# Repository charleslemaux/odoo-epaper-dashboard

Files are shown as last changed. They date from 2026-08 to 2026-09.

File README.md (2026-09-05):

# Odoo e-Paper Dashboard — Pico 2 W, C firmware

Bare-metal C rewrite (Pico SDK, no OS, no dynamic allocation in project
code) of a MicroPython prototype. A Raspberry Pi Pico 2 W joins your WiFi,
authenticates against a self-hosted Odoo instance over HTTPS, and shows
the signed-in user's scheduled Activities (`mail.activity` — the items
behind the clock icon in Odoo's top bar, attached to any record: a
contact, an invoice, a task...) on a Waveshare 7.3" e-Paper HAT
(E) — Spectra 6, 800x480, 6 fixed colors (black, white, yellow, red,
blue, green).

It polls Odoo's JSON-RPC API every 5 minutes but only spends a physical
refresh cycle on the panel when the activity list actually changed, or once
a day for a mandatory health refresh. Spectra 6 panels have no
partial-refresh mode, so minimizing wear means minimizing *refreshes*,
not minimizing pixels touched. Everything runs from a single superloop
with static buffers; the only dynamic allocation anywhere is mbedTLS's
internal handshake scratch space, freed right after each TLS handshake.

Screen layout (800x480 — 72px banner with 48px title, seven 48px rows
of 32px text, 32px footer; rendered by the firmware's own code via
`make -C tests preview.exe`):

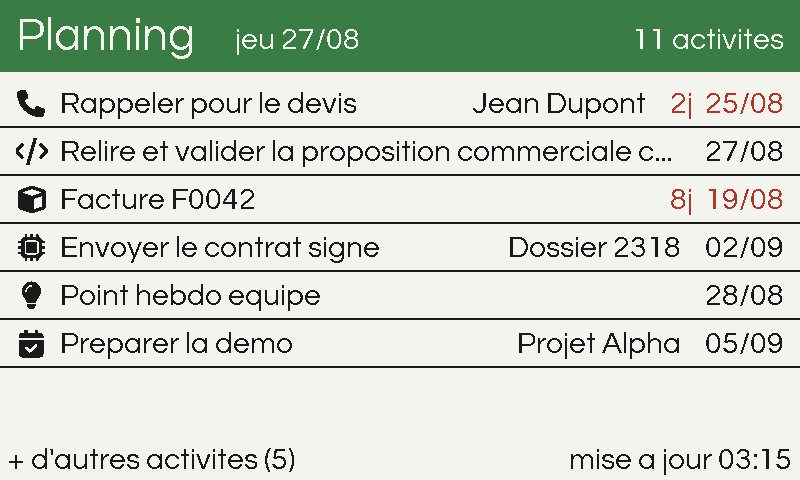
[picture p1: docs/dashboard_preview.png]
Dashboard layout


Each row starts with a 32px icon mirroring the Font Awesome icon
configured on the activity type in Odoo itself (the firmware fetches
each activity's `icon` class and maps it in `src/app/activity_icon.c`;
unknown classes fall back to a clock), then the
activity's summary (or, when the activity has no summary, the name of
the record it is attached to). The deadline (always visible, far
right) stays black until the date has passed and turns red once it
has, joined by a compact red day counter (`8j`). The text has priority
over the row: if it is too long it is truncated with `...`, otherwise
the remaining width shows the related record, right-aligned. Bold
full-width separators divide the rows. The banner counter shows the
real total of scheduled activities (fetched with a `search_count`
alongside the row query), and when more exist than the seven visible
rows the footer says how many are hidden: `+ d'autres activites (N)`. The footer shows the timestamp
of the last *screen update*, not a live clock (a ticking clock would
force a refresh every minute, defeating the whole point).

Text is set in [Questrial](https://fonts.google.com/specimen/Questrial)
(SIL Open Font License 1.1 — see `lib/questrial/OFL.txt`), pre-rendered
at build time into 32 px and 48 px proportional bitmap glyphs
(`src/gfx/font_data.c`, generated by `tools/gen_font.py`) since the
panel firmware has no TTF rasterizer. To change the font, drop a new
TTF in `lib/` and run
`python tools/gen_font.py lib/yourfont/YourFont.ttf`.

Activity-type icons are rasterized the same way from
[Font Awesome Free](https://fontawesome.com) solid glyphs (icons
CC BY 4.0, font SIL OFL 1.1 — see `lib/fontawesome/LICENSE.txt`) by
`tools/gen_icons.py` into `src/gfx/icon_data.c`. To support a new
custom activity type: add its glyph codepoint to `tools/gen_icons.py`,
its `fa-...` class to the table in `src/app/activity_icon.c`, rerun
the generator, and rebuild.

## 1. Hardware and wiring

- MCU: Raspberry Pi Pico 2 W (RP2350, 520 KB SRAM, CYW43439 WiFi). The
  "2 WH" (pre-soldered headers) variant is identical firmware-wise.
- Panel: Waveshare 7.3" e-Paper HAT (E), Spectra 6, 800x480.
- Bus: 4-wire SPI, but driven as bit-banged GPIO on purpose — hardware
  SPI at >= 1 MHz corrupts commands on this wiring (Dupont wires +
  ribbon cable). Do not "optimize" this back to hardware SPI without
  re-validating on real hardware; see `DRIVER_REFERENCE.md` section 2.
- **SPI Select switch on the HAT must be on 0.**

| Signal | Pico pin | Constant |
|---|---|---|
| VCC | 3V3 OUT (pin 36) | — |
| GND | GND | — |
| DIN | GP11 | `DIN_PIN`  |
| CLK | GP10 | `CLK_PIN`  |
| CS | GP9 | `CS_PIN` |
| DC | GP8 | `DC_PIN` |
| RST | GP12 | `RST_PIN`  |
| BUSY | GP13 | `BUSY_PIN` |

Panel safety rules, all enforced in the firmware but worth knowing:

- `epd_sleep()` is called after every refresh, on every code path
  including failures. Leaving the panel powered outside sleep mode
  holds it at high internal voltage and causes irreversible damage.
- At least 3 minutes between refreshes (`REFRESH_MIN_GAP_S = 180`).
- At least one refresh every 24 hours while powered
  (`REFRESH_MAX_AGE_S = 86400`).
- One `epd_display()` per fully-composed frame — never partial sends.

## 2. Toolchain setup, from zero

These are the packages the firmware actually needs to cross-compile for
the Pico 2 W (PowerShell, run as your normal user — no admin needed for
winget user-scope installs):

```powershell
winget install -e --id Kitware.CMake --accept-source-agreements --accept-package-agreements
winget install -e --id Ninja-build.Ninja --accept-package-agreements
winget install -e --id Arm.GnuArmEmbeddedToolchain --accept-package-agreements
```

Clone the Pico SDK (2.3.0 or any later stable 2.x tag) with its four
required submodules — the SDK itself is much bigger than these four, but
only these are needed for this project's WiFi/lwIP/mbedTLS/USB stack:

```powershell
git clone --depth 1 --branch 2.3.0 https://github.com/raspberrypi/pico-sdk.git $env:USERPROFILE\pico-sdk
cd $env:USERPROFILE\pico-sdk
git submodule update --init --depth 1 lib/cyw43-driver lib/lwip lib/mbedtls lib/tinyusb
```

Point the SDK at the ARM toolchain and the checkout (adjust the version
folder in the ARM path to whatever winget actually installed —
`Get-ChildItem 'C:\Program Files (x86)\Arm GNU Toolchain arm-none-eabi'`
will show it):

```powershell
[Environment]::SetEnvironmentVariable('PICO_SDK_PATH', "$env:USERPROFILE\pico-sdk", 'User')
[Environment]::SetEnvironmentVariable('PICO_TOOLCHAIN_PATH', 'C:\Program Files (x86)\Arm GNU Toolchain arm-none-eabi\14.2 rel1\bin', 'User')
```

Open a new terminal (persisted User environment variables are not
picked up by already-running shells), then verify:

```powershell
cmake --version
ninja --version
arm-none-eabi-gcc --version
```

Note: an earlier draft of this setup called for a bundled host
toolchain ("w64devkit") alongside the ARM one. That package does not
exist in the winget catalog, and the firmware itself never needs a host
compiler — CMake cross-compiles everything with the ARM toolchain
above. A host C compiler is only needed for two things, both covered
below: running the unit tests under `tests/`, and (rarely) building
`picotool` from source during the very first `cmake --build`.

### Host compiler for tests

`tests/` builds and runs on your PC, not the Pico, so it needs a plain
host C compiler and `make`. Any working gcc or clang is fine. On this
project's development machine, the obvious winget substitute for a host
gcc (`BrechtSanders.WinLibs.POSIX.UCRT`) turned out to have a bundled
assembler (`as.exe`) that Windows Smart App Control silently blocks
when it's invoked as a subprocess — which breaks every build that
depends on it, tests included, with a confusing "CreateProcess: No such
file or directory" error that has nothing to do with the actual code.
`clang` was installed as a working substitute instead:

```powershell
winget install -e --id LLVM.LLVM --accept-package-agreements
```

and tests are run with `CC=clang` (see "Host tests" below). If your
system gcc already works cleanly, plain `make -C tests run` is fine —
there is nothing gcc-specific about the test code.

## 3. Configuration

Copy the template and fill in real values — `include/config.h` is
gitignored from the first commit, so credentials can never be committed
by accident:

```powershell
cp config.h.example include/config.h
```

Fields, in the order they appear in `config.h.example`:

| Macro | Meaning |
|---|---|
| `WIFI_SSID` / `WIFI_PASSWORD` | Your WiFi network credentials. |
| `WIFI_COUNTRY` | A `CYW43_COUNTRY_*` constant from the Pico SDK (e.g. `CYW43_COUNTRY_FRANCE`); affects the legal WiFi channel set. |
| `ODOO_HOST` | Odoo hostname only — no `https://`, no path. |
| `ODOO_PORT` | HTTPS port, normally `443`. |
| `ODOO_DB` | Odoo database name. |
| `ODOO_LOGIN` | Your Odoo login (usually an email address). |
| `ODOO_API_KEY` | An Odoo API key (not your account password — see below). |
| `ODOO_ACTIVITY_DOMAIN` | A JSON-RPC domain filter on `mail.activity`, as a C string with `%d` where the authenticated `uid` goes (see below). |
| `POLL_INTERVAL_S` | Seconds between Odoo polls, default 300 (5 minutes). |
| `NTP_SERVER` | SNTP server for time sync, e.g. `pool.ntp.org`. |
| `TZ_OFFSET_MIN` | Local timezone offset from UTC, in minutes (no DST database — a plain fixed offset, adjust by hand across DST changes). |
| `EPD_CLK_HALF_PERIOD_US` | Bit-bang clock half-period in microseconds. Default `1` (~500 kHz effective). Do not lower this without re-validating on real hardware — see the SPI corruption warning in section 1. |

`ODOO_CA_CERT` is not in the template's macro list; it is documented as
an optional addition in a comment at the bottom of
`config.h.example` — see "Optional: pinning the Odoo CA certificate"
below.

**Keep `"` out of every config value.** All of these are compiled as C
string literals; an unescaped `"` inside a password, login, or hostname
will break the build (or silently truncate the value at best).

### Creating an Odoo API key

Use an API key, not your login password: in Odoo, click your user
avatar (top right) -> **My Profile** -> **Account Security** tab ->
**New API Key**. Give it a description, confirm, and copy the key
immediately — Odoo only shows it once.

### Tuning `ODOO_ACTIVITY_DOMAIN`

The domain is a JSON-RPC filter on `mail.activity`, `printf`-substituted
at request-build time: `%d` is replaced with the `uid` returned by
`authenticate`. The default,

```c
#define ODOO_ACTIVITY_DOMAIN "[[\"user_id\",\"=\",%d]]"
```

fetches exactly what Odoo's systray clock shows: every activity
scheduled for the signed-in user, on any record, ordered by deadline
(activities always carry one). To narrow it, extend the domain — for
example, only activities on contacts:

```c
#define ODOO_ACTIVITY_DOMAIN "[[\"user_id\",\"=\",%d],[\"res_model\",\"=\",\"res.partner\"]]"
```

No firmware code needs to change for this — it's a config-only edit.

## 4. Optional: pinning the Odoo CA certificate

By default `ODOO_CA_CERT` is undefined, which means TLS still encrypts
the connection but does **not** verify the server's identity — a LAN
man-in-the-middle could intercept the connection and read your Odoo API
key. To pin the CA and get full certificate verification, fetch the
certificate chain:

```
openssl s_client -connect ODOO_HOST:443 -showcerts
```

(run from Git Bash or WSL if `openssl` isn't on your Windows PATH).
Take the **last** `-----BEGIN CERTIFICATE-----` ... `-----END
CERTIFICATE-----` block printed (the top of the chain, i.e. the issuing
CA), and turn it into a single C string with explicit `\n` line breaks:

```c
#define ODOO_CA_CERT "-----BEGIN CERTIFICATE-----\n" \
    "MIIB...\n" \
    "...\n" \
    "-----END CERTIFICATE-----\n"
```

Add this to your local `include/config.h`. That file is gitignored and
is explicitly exempted from the project's single-line-macro style rule
for exactly this reason (see the comment in `config.h.example`) — a
multi-line PEM string is fine there.

## 5. Build and flash

```powershell
cmake -S . -B build -G Ninja
cmake --build build
```

The build fails fast with a clear `#error` if `include/config.h` is
missing (see section 3). The first configure also downloads and builds
`picotool` from source — needed to turn the linked ELF into
`.uf2`/`.bin`/`.hex` for RP2350 — which requires a working **native**
host C/C++ compiler (not the ARM cross toolchain). If that host
compiler is broken (this project hit exactly the Smart App
Control/`as.exe` issue described in section 2 here too, since picotool
also tried to use the WinLibs GCC install), build `picotool` once with
any other working host compiler (e.g. MSVC's `cl.exe`, if Visual Studio
is installed) and point CMake at the prebuilt install instead of
letting it build from source:

```powershell
cmake -S build/_deps/picotool-src -B <picotool-build-dir> -G Ninja `
    -DCMAKE_C_COMPILER=cl -DCMAKE_CXX_COMPILER=cl -DPICOTOOL_NO_LIBUSB=1 `
    -DPICO_SDK_PATH=$env:PICO_SDK_PATH `
    -DCMAKE_INSTALL_PREFIX=<picotool-install-dir> -DCMAKE_BUILD_TYPE=Release
cmake --build <picotool-build-dir> --config Release
cmake --install <picotool-build-dir> --config Release
Remove-Item -Recurse -Force build
cmake -S . -B build -G Ninja -DCMAKE_PREFIX_PATH="<picotool-install-dir>"
```

The configure log will then say `Using picotool from
<picotool-install-dir>/bin/picotool.exe` instead of building it from
source, and `cmake --build build` proceeds normally.

To flash: hold **BOOTSEL**, plug the Pico 2 W into USB, release BOOTSEL
once it shows up as a mass-storage drive (`RP2350`), then drag-and-drop
`build/epaper_dashboard.uf2` onto that drive. The board reboots and
starts running the firmware automatically.

Open a serial monitor at **115200 baud** on the Pico's USB serial port
to watch the staged boot log (WiFi connect, SNTP sync, Odoo
authenticate, task count, refresh decisions).

## 6. Host tests

```
make -C tests run
```

builds and runs the ten host-side unit test binaries (`test_harness`,
`test_json_str`, `test_odoo_parse`, `test_odoo_request`,
`test_time_fmt`, `test_http_util`, `test_refresh`, `test_gfx`,
`test_gfx_text`, `test_dashboard`) — plain C, no Pico SDK dependency,
covering `odoo_parse` against canned JSON (nominal tasks, empty list,
Odoo error objects, truncated JSON, oversized fields, accented text),
the refresh-decision matrix, graphics primitives, and dashboard layout.

On this project's development machine, plain `make -C tests run` fails
for the same Smart App Control reason described in section 2 (the
WinLibs GCC substitute's assembler is blocked), so tests were actually
run with:

```
make -C tests CC=clang run
```

Expect every line to read `<name>: OK` and the command to exit 0.

## 7. Behavior reference

- After boot (WiFi connect with exponential backoff, 5 s doubling to an
  80 s cap; SNTP time sync; one Odoo `authenticate` call caching the
  `uid`), the firmware polls Odoo's JSON-RPC API every
  `POLL_INTERVAL_S` seconds (default 300 = 5 minutes).
- The panel is refreshed only when the fetched task snapshot actually
  changed, or at least once per 24 hours, and never less than 3 minutes
  after the previous refresh — otherwise the display is left untouched
  and the panel takes zero wear.
- Three consecutive failed polls count as a state change: the firmware
  forces one refresh showing an offline footer (`HORS LIGNE depuis
  HH:MM`, in red). The next successful poll forces a refresh back to
  the normal view.
- A hardware watchdog (8 s) reboots the board if any code path stops
  feeding it — the WiFi connect/retry loop, the inter-poll idle wait,
  and the panel's busy-wait loop all feed it periodically, so normal
  operation never trips it; only a genuine hang does.
- If the WiFi chip itself fails to initialize at boot (before any SSID
  or password is even used), the onboard LED fast-blinks (on/off every
  100 ms) forever and the firmware never proceeds further. That pattern
  always means the WiFi chip did not come up — not a wrong SSID or
  password, which instead shows as an endless "wifi: retry" backoff in
  the serial log.
- The dashboard renders ASCII only: the vendored font has no accented
  glyphs, so French accented characters coming back from Odoo (é, è,
  à, ç, ...) are folded to their unaccented equivalent while parsing the
  JSON response; any other multi-byte UTF-8 sequence becomes `?`.

## 8. Troubleshooting

- **Panel completely unresponsive** (serial log shows "epd: panel not
  responding", or a boot-time `RuntimeError` in the MicroPython
  reference): almost always a loose Dupont wire on CLK/DIN/DC/CS, or
  the SPI Select switch not on 0. Full diagnostic order in
  `DRIVER_REFERENCE.md` section 6.
- **Text renders wrong or a glyph looks broken**: the font is
  pre-rendered bitmap data generated from the TTF — regenerate with
  `python tools/gen_font.py lib/questrial/Questrial-Regular.ttf` after
  any font change, then rebuild.
- **Build fails with `include/config.h missing`**: see section 3 — copy
  `config.h.example` there and fill it in.
- **LED fast-blinks forever right after power-on**: WiFi chip init
  failure (see "Behavior reference" above) — check the board/antenna,
  this is not a credentials problem.
- **Offline footer shows even though WiFi is clearly up**: check
  `ODOO_HOST`/`ODOO_PORT`/`ODOO_DB`/`ODOO_LOGIN`/`ODOO_API_KEY`, and
  whether `ODOO_ACTIVITY_DOMAIN` only uses `mail.activity` fields
  (see "Tuning `ODOO_ACTIVITY_DOMAIN`" in section 3).

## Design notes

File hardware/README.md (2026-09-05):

# Desk stand — Waveshare 7.3" e-Paper (E) + Pico 2 W (Rev 2.1)

Four flat 3D-printed parts, zero supports, zero glue, zero screws.
Every insertion path (not just the final positions) is verified by
boolean sweeps in `fusion_scripts/r8_motion.py` — if a part couldn't
physically slide or drop into place, the build fails loudly.

**How it goes together (all joints are slides or drop-ins):**

1. **panel → frame**: slides down from the frame's open top edge in
   its own plane, seats on the bottom ledge (exact vertical position),
   four side ribs center it with a light scratch-fit.
2. **plate → frame**: slides down the channel just behind the panel,
   dome-side toward the glass, under the side lips, clicks past two
   detents onto the stops. The six domes press the panel gently.
3. **screen module → base**: drops into the full-width 12° slot;
   gravity holds it; the ribbon falls through the notch behind the
   slot into the box.
4. **HAT / Pico → base**: drop into their fenced, labeled bays with
   all cables attached (HAT rests on two pedestals so its 40-pin
   socket hangs free; Pico lies loose; micro-USB cable exits the notch
   in the right wall).
5. **lid → base**: slides in through the rear-wall door until it hits
   the front stops; its ridge tail stays outside as the grip.

| File | What |
|---|---|
| `print/epaper73_H2C_PLA.3mf` | **Open in Bambu Studio → Slice → Print.** 4 parts arranged, H2C 0.4, 0.20mm Standard, Bambu PLA Basic, Textured PEI, supports OFF |
| `print/epaper73_*_print.stl` | Same four parts as pre-oriented STLs |
| `epaper73_case.step` | Full CAD + named `proxy_*` hardware reference bodies |
| `fusion_scripts/` | Regenerate/verify: `reset.py` → `r1_screen.py` → `r2_base.py` → `r3_check.py` (seated interference) → `r8_motion.py` (insertion sweeps) → `r4_export.py` → `make_print_meshes.py`. `r9_debug.py` probes material at specific spots; `r5/r6/r7/vis` pose explanatory views |

Window geometry uses the panel's real active-area offsets (borders
5.1 L/R, 4.7 top, 10.5 bottom per the Waveshare drawing) with the
panel *seated on the ledge*, so the visible area is deterministic.

## Printing (H2C, PLA)

All parts print as placed, flat side down, **no supports** (the only
overhangs are two 2.2 mm lip bridges in the frame and short lip strips
in the base — trivial bridging for the H2C). Keep filament shrinkage
at 100% and don't rescale; FDM clearances are modeled in: panel
+0.8/side (ribs re-center it), plate 0.5, screen slot 0.8, lid 0.2
thickness play, bays ≥0.8.

## Tuning (one constant each)

- Panel slides too hard/loose → rib reach in `r1_screen.py`
  (`85.0` in the rib boxes; ribs crush 0.1 nominal).
- Plate click too weak/strong → detent bump reach (`CH_X - 0.4`).
- Screen wobbles in slot → `SLOT_Y0/SLOT_Y1` in `r2_base.py` (gap 8.4
  vs frame 7.6).
- Lid slides hard → `LID_W` (175.0 in 175.2) or the door cut (±87.7).
- White border visible → `WIN_V0/WIN_V1/WIN_X` (active +0.8 reveal).

To reflash the Pico: slide the lid out, press BOOTSEL, replug.

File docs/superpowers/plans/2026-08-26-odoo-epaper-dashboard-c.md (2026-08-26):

# Odoo e-Paper Dashboard (C firmware) Implementation Plan

> **For agentic workers:** REQUIRED SUB-SKILL: Use superpowers:subagent-driven-development (recommended) or superpowers:executing-plans to implement this plan task-by-task. Steps use checkbox (`- [ ]`) syntax for tracking.

**Goal:** Bare-metal C firmware for a Raspberry Pi Pico 2 W that polls a self-hosted Odoo over HTTPS every 5 minutes and shows the user's open tasks on a Waveshare 7.3" Spectra-6 e-paper panel, refreshing only when data changes.

**Architecture:** Single-threaded superloop on the Pico SDK (`pico_cyw43_arch_lwip_poll`), lwIP `altcp_tls` + mbedTLS for HTTPS, hand-rolled HTTP/1.0 POST client, JSON-RPC to Odoo, jsmn-based parsing, custom 4bpp framebuffer graphics, and a C port of the validated MicroPython bit-bang panel driver (paced to ~500 kHz).

**Tech Stack:** Pico SDK 2.x (board `pico2_w`), CMake + Ninja + arm-none-eabi-gcc, lwIP, mbedTLS, jsmn (vendored), font8x8 (vendored), host tests via w64devkit gcc + make.

**Spec:** `docs/superpowers/specs/2026-08-26-odoo-epaper-dashboard-c-design.md`

## Global Constraints

- **Epitech C Coding Style v7 applies to every `.c`/`.h` in `src/`, `include/`, `tests/` and to `tests/Makefile`.** Vendored code in `lib/` is exempt. Key rules (violations are task failures):
  - snake_case everywhere; typedefs end `_t`; macros/global constants/enum members UPPER_SNAKE_CASE.
  - ≤ 80 columns; 4-space indent, never tabs (C files); LF line endings; no trailing spaces; file ends with exactly one newline.
  - Function bodies ≤ 20 lines; ≤ 4 parameters; per `.c` file ≤ 5 exported and ≤ 10 total functions; functions with no params take `void`.
  - Variables declared at top of function, one per statement, one blank line after declarations, no other blank lines inside functions; no comments inside function bodies.
  - Structs passed by pointer (C-F7); pointer `*` sticks to the name (C-V3); `const` wherever the data isn't modified (C-A1).
  - `if/else if/else` ≤ 3 branches; nesting depth ≤ 2 (an `else if` counts as 2); no `goto`; ternaries only simple and value-used.
  - Structure/enum declarations, prototypes, macros live in headers only (C-H1); include guards `#ifndef NAME_H_` (never `#pragma once`); preprocessor directives indented 4 spaces per level of *directive* nesting, independent of C code (C-G3).
  - Global variables forbidden; use `static` locals inside functions for persistent buffers; file-local helpers are `static` (C-A4). `static const` lookup tables inside `.c` files are accepted.
  - One statement per line (C-L1); exactly one empty line between function definitions (C-G2).
- **Every** `.c`/`.h` file starts with this exact header (adapt the description line):

```c
/*
** EPITECH PROJECT, 2026
** epaper_dashboard
** File description:
** <one-line description of the file>
*/
```

  `tests/Makefile` uses the `##` comment variant of the same header.
- **No dynamic allocation in project code.** Large/persistent buffers are `static` locals. mbedTLS allocates internally — that's allowed.
- **Build gates:** host-testable modules must pass `make -C tests run` (gcc, `-Wall -Wextra -Werror`); firmware tasks must produce `build/epaper_dashboard.uf2` via `cmake --build build`. Firmware compiles with `-Wall -Wextra` (no `-Werror` — SDK sources compile inside our target).
- **Hardware checkpoints** are marked `[HW]`: build the .uf2, then ask the user to flash (BOOTSEL drag-drop) and paste serial output. Do NOT block later software tasks on `[HW]` confirmation — continue and batch hardware validation at Task 19.
- **Environment facts** (verified 2026-08-26): Windows 11; `winget` and `python` (3.13) available; `cmake`, `ninja`, `arm-none-eabi-gcc`, `gcc`, `make` all missing; no pico-sdk anywhere. `winget`/env-var commands run in PowerShell; git/curl/build commands work in Bash. After `[Environment]::SetEnvironmentVariable(...,'User')`, also set the variable in the current session (`$env:X = ...`) — new values don't apply retroactively.
- **Documented deviations from the spec** (approved rationale, reconcile in spec later if desired):
  1. TLS certificate *time-validity* is not checked (`MBEDTLS_HAVE_TIME` off — avoids newlib clock syscall plumbing); CA chain + SNI hostname are still verified when `ODOO_CA_CERT` is set. SNTP remains required for dates/clock display.
  2. Footer overflow indicator is the generic `+ d'autres taches` (an exact `+N` would need a second Odoo query, out of scope).
  3. `ODOO_CA_CERT` is *defined-or-absent* in `config.h` (checked with `#ifdef`) instead of a `NULL` sentinel — avoids `-Waddress` warnings.
  4. Extra files beyond the spec's list, forced by the ≤10-functions rule: `jsmn_util.c`, `http_conn.c`, `sys_idle.c`, `include/app.h`.

---

### Task 1: Toolchain bootstrap

**Files:** none in repo (installs tools, clones SDK, sets env vars).

**Interfaces:**
- Consumes: nothing.
- Produces: working `cmake`, `ninja`, `arm-none-eabi-gcc`, host `gcc` + `make`; `C:\Users\charl\pico-sdk` with submodules; user env vars `PICO_SDK_PATH`, `PICO_TOOLCHAIN_PATH`.

- [ ] **Step 1: Install the four toolchain packages (PowerShell)**

```powershell
winget install -e --id Kitware.CMake --accept-source-agreements --accept-package-agreements
winget install -e --id Ninja-build.Ninja --accept-package-agreements
winget install -e --id Arm.GnuArmEmbeddedToolchain --accept-package-agreements
winget install -e --id skeeto.w64devkit --accept-package-agreements
```

If a winget ID is not found, search (`winget search cmake`, `winget search "arm gnu"`, `winget search w64devkit`) and install the matching package. Any working host gcc+make (e.g. MSYS2) is an acceptable substitute for w64devkit.

- [ ] **Step 2: Wire up PATH / env vars (PowerShell)**

Ninja lands in `%LOCALAPPDATA%\Microsoft\WinGet\Links` (already on PATH). CMake installs to `C:\Program Files\CMake\bin` — add to user PATH if `cmake --version` fails. Then:

```powershell
$armRoot = 'C:\Program Files (x86)\Arm GNU Toolchain arm-none-eabi'
$arm = (Get-ChildItem $armRoot | Sort-Object Name | Select-Object -Last 1).FullName + '\bin'
[Environment]::SetEnvironmentVariable('PICO_TOOLCHAIN_PATH', $arm, 'User')
$w64 = (Get-ChildItem "$env:LOCALAPPDATA\Microsoft\WinGet\Packages" -Directory -Filter '*w64devkit*' | Select-Object -First 1).FullName
$w64bin = (Get-ChildItem $w64 -Recurse -Directory -Filter bin | Select-Object -First 1).FullName
[Environment]::SetEnvironmentVariable('Path', [Environment]::GetEnvironmentVariable('Path','User') + ';' + $w64bin, 'User')
```

Adapt discovery paths to what the installers actually did (`Get-ChildItem` first). Also set `$env:Path`/`$env:PICO_TOOLCHAIN_PATH` in-session before verifying.

- [ ] **Step 3: Clone the Pico SDK (Bash)**

```bash
git ls-remote --tags https://github.com/raspberrypi/pico-sdk.git | grep -o 'refs/tags/2\.[0-9.]*$' | sort -V | tail -3
# pick the highest stable 2.x.y tag printed, e.g. 2.1.1:
git clone --depth 1 --branch <TAG> https://github.com/raspberrypi/pico-sdk.git /c/Users/charl/pico-sdk
cd /c/Users/charl/pico-sdk
git submodule update --init --depth 1 lib/cyw43-driver lib/lwip lib/mbedtls lib/tinyusb
```

```powershell
[Environment]::SetEnvironmentVariable('PICO_SDK_PATH', 'C:\Users\charl\pico-sdk', 'User')
```

- [ ] **Step 4: Verify everything**

Run (fresh env in-session): `cmake --version`, `ninja --version`, `arm-none-eabi-gcc --version` (use `$env:PICO_TOOLCHAIN_PATH\arm-none-eabi-gcc.exe` if not on PATH — that's fine, the SDK uses the env var), `gcc --version`, `make --version`, `ls $env:PICO_SDK_PATH/pico_sdk_init.cmake`.
Expected: all print versions / the file exists. Nothing to commit.

---

### Task 2: Repository scaffold

**Files:**
- Create: `.gitattributes`, `config.h.example`, `micropython/` (moved files)
- Modify: none.

**Interfaces:**
- Consumes: nothing.
- Produces: `config.h.example` — the exact macro set every later module's `#include "config.h"` relies on.

- [ ] **Step 1: Move MicroPython reference files (Bash)**

```bash
cd /c/Users/charl/Documents/GitHub/e-paper_pico-2W
mkdir -p micropython src include lib tests
git mv main.py dashboard.py tutorial.md micropython/
```

(`DRIVER_REFERENCE.md` stays at repo root — it documents hardware truth the C driver uses.)

- [ ] **Step 2: Create `.gitattributes`**

```
* text=auto
*.c text eol=lf
*.h text eol=lf
*.md text eol=lf
*.py text eol=lf
Makefile text eol=lf
CMakeLists.txt text eol=lf
*.cmake text eol=lf
```

- [ ] **Step 3: Create `config.h.example`**

```c
/*
** EPITECH PROJECT, 2026
** epaper_dashboard
** File description:
** Configuration template: copy to include/config.h and fill in real values
*/

#ifndef CONFIG_H_
    #define CONFIG_H_

#define WIFI_SSID "MyNetwork"
#define WIFI_PASSWORD "MyPassword"
#define WIFI_COUNTRY CYW43_COUNTRY_FRANCE
#define ODOO_HOST "odoo.example.com"
#define ODOO_PORT 443
#define ODOO_DB "mydb"
#define ODOO_LOGIN "me@example.com"
#define ODOO_API_KEY "paste-api-key-here"
#define ODOO_TASK_DOMAIN "[[\"user_ids\",\"in\",[%d]],[\"is_closed\",\"=\",false]]"
#define POLL_INTERVAL_S 300
#define NTP_SERVER "pool.ntp.org"
#define TZ_OFFSET_MIN 120
#define EPD_CLK_HALF_PERIOD_US 1

/*
** Optional: TLS certificate pinning. When ODOO_CA_CERT is NOT defined the
** connection is encrypted but the server certificate is NOT verified.
** To pin your CA, define it as one C string with \n separators, e.g.:
** #define ODOO_CA_CERT "-----BEGIN CERTIFICATE-----\nMIIB...\n" \
**     "...\n-----END CERTIFICATE-----\n"
** (Your personal include/config.h is gitignored and exempt from the
** single-line-macro style rule.)
*/

#endif /* !CONFIG_H_ */
```

- [ ] **Step 4: Commit**

```bash
git add .gitattributes config.h.example
git commit -m "chore: scaffold repo layout, line-ending policy and config template"
```

(Include the standard trailer block from Global Constraints in this and every commit.)

---

### Task 3: Firmware skeleton builds a .uf2

**Files:**
- Create: `CMakeLists.txt`, `pico_sdk_import.cmake` (copied from SDK), `src/main.c` (stub, replaced in Tasks 15/19).

**Interfaces:**
- Consumes: Task 1 toolchain + `PICO_SDK_PATH`.
- Produces: `build/epaper_dashboard.uf2`; the CMake target `epaper_dashboard` that later tasks extend.

- [ ] **Step 1: Copy the SDK import shim (Bash)**

```bash
cp "$PICO_SDK_PATH/external/pico_sdk_import.cmake" pico_sdk_import.cmake
```

- [ ] **Step 2: Create `CMakeLists.txt`**

```cmake
cmake_minimum_required(VERSION 3.13)

set(PICO_BOARD pico2_w CACHE STRING "Board type")
include(pico_sdk_import.cmake)

project(epaper_dashboard C CXX ASM)
set(CMAKE_C_STANDARD 11)

pico_sdk_init()

add_executable(epaper_dashboard
    src/main.c
)

target_include_directories(epaper_dashboard PRIVATE
    ${CMAKE_CURRENT_LIST_DIR}
    ${CMAKE_CURRENT_LIST_DIR}/include
    ${CMAKE_CURRENT_LIST_DIR}/lib/jsmn
    ${CMAKE_CURRENT_LIST_DIR}/lib/font8x8
)

target_compile_options(epaper_dashboard PRIVATE -Wall -Wextra)

target_link_libraries(epaper_dashboard
    pico_stdlib
)

pico_enable_stdio_usb(epaper_dashboard 1)
pico_enable_stdio_uart(epaper_dashboard 0)
pico_add_extra_outputs(epaper_dashboard)
```

- [ ] **Step 3: Create stub `src/main.c`**

```c
/*
** EPITECH PROJECT, 2026
** epaper_dashboard
** File description:
** Entry point (toolchain-check stub, replaced by the real superloop later)
*/

#include <stdio.h>
#include "pico/stdlib.h"

int main(void)
{
    stdio_init_all();
    for (;;) {
        printf("epaper_dashboard: toolchain OK\n");
        sleep_ms(1000);
    }
    return 0;
}
```

- [ ] **Step 4: Build**

```bash
cmake -S . -B build -G Ninja
cmake --build build
ls build/epaper_dashboard.uf2
```

Expected: `.uf2` exists. First configure downloads picotool — allow it.

- [ ] **Step 5 [HW]:** Offer the user to flash this stub (BOOTSEL drag-drop, serial monitor 115200 should print `toolchain OK`). Do not block on it.

- [ ] **Step 6: Commit**

```bash
git add CMakeLists.txt pico_sdk_import.cmake src/main.c
git commit -m "feat: minimal Pico 2 W firmware skeleton builds a uf2"
```

---

### Task 4: Vendored libraries + host test harness

**Files:**
- Create: `lib/jsmn/jsmn.h`, `lib/font8x8/font8x8_basic.h`, `tests/Makefile`, `tests/test_config/config.h`, `tests/test_harness.c`.

**Interfaces:**
- Consumes: host gcc + make (Task 1).
- Produces: `make -C tests run` convention; `tests/test_config/config.h` fake credentials all request-builder tests compile against; jsmn (`jsmntok_t`, `jsmn_parse`) and `font8x8_basic[128][8]` for later tasks.

- [ ] **Step 1: Vendor the two single-header libraries (Bash)**

```bash
curl -fsSL https://raw.githubusercontent.com/zserge/jsmn/master/jsmn.h -o lib/jsmn/jsmn.h
curl -fsSL https://raw.githubusercontent.com/dhepper/font8x8/master/font8x8_basic.h -o lib/font8x8/font8x8_basic.h
grep -q jsmn_parse lib/jsmn/jsmn.h && grep -q font8x8_basic lib/font8x8/font8x8_basic.h && echo VENDOR_OK
```

Expected: `VENDOR_OK`. (jsmn: MIT license; font8x8: public domain — keep their headers intact. `font8x8_basic.h` defines a non-static array: it must be included by exactly one `.c` file, `src/gfx_text.c`.)

- [ ] **Step 2: Create `tests/test_config/config.h`** (fake credentials, same shape as `config.h.example`)

```c
/*
** EPITECH PROJECT, 2026
** epaper_dashboard
** File description:
** Fake configuration used by host-side unit tests only
*/

#ifndef CONFIG_H_
    #define CONFIG_H_

#define WIFI_SSID "test-ssid"
#define WIFI_PASSWORD "test-pass"
#define ODOO_HOST "odoo.test.lan"
#define ODOO_PORT 443
#define ODOO_DB "testdb"
#define ODOO_LOGIN "tester@test.lan"
#define ODOO_API_KEY "test-key"
#define ODOO_TASK_DOMAIN "[[\"user_ids\",\"in\",[%d]]]"
#define POLL_INTERVAL_S 300
#define NTP_SERVER "pool.ntp.org"
#define TZ_OFFSET_MIN 120
#define EPD_CLK_HALF_PERIOD_US 1

#endif /* !CONFIG_H_ */
```

- [ ] **Step 3: Create `tests/test_harness.c`** (proves the harness itself works)

```c
/*
** EPITECH PROJECT, 2026
** epaper_dashboard
** File description:
** Smoke test proving the host test harness compiles and runs
*/

#include <assert.h>
#include <stdio.h>
#include "config.h"

int main(void)
{
    assert(ODOO_PORT == 443);
    printf("test_harness: OK\n");
    return 0;
}
```

- [ ] **Step 4: Create `tests/Makefile`**

```make
##
## EPITECH PROJECT, 2026
## epaper_dashboard
## File description:
## Host-side unit test build and runner (gcc + make from w64devkit)
##

CC = gcc
CFLAGS = -Wall -Wextra -Werror -std=gnu11 -Itest_config -I../include \
	-I../lib/jsmn -I../lib/font8x8

TESTS = test_harness

all: $(addsuffix .exe,$(TESTS))

test_harness.exe: test_harness.c
	$(CC) $(CFLAGS) -o $@ $^

run: all
	for t in $(TESTS); do ./$$t.exe || exit 1; done

clean:
	rm -f *.exe
```

(Recipe lines use real tabs — mandatory in make. Each later task appends its own rule and extends `TESTS`.)

- [ ] **Step 5: Run** `make -C tests run` — Expected: `test_harness: OK`.

- [ ] **Step 6: Commit**

```bash
git add lib tests
git commit -m "feat: vendor jsmn and font8x8, add host test harness"
```

---

### Task 5: `json_str` — JSON string extraction with ASCII folding

**Files:**
- Create: `include/json_str.h`, `src/json_str.c`, `tests/test_json_str.c`
- Modify: `tests/Makefile`

**Interfaces:**
- Consumes: nothing (pure C, no Pico deps).
- Produces: `void json_str_fold(char *dst, size_t size, char const *src, size_t len);` — decodes a raw JSON string token (`src`/`len` = bytes between the quotes, escapes intact), folds UTF-8 and `\uXXXX` to ASCII (é→e, œ→oe, …), always NUL-terminates, and marks truncation by making the last kept char `'.'`.

- [ ] **Step 1: Write the failing test `tests/test_json_str.c`**

```c
/*
** EPITECH PROJECT, 2026
** epaper_dashboard
** File description:
** Unit tests for JSON string extraction and ASCII folding
*/

#include <assert.h>
#include <stdio.h>
#include <string.h>
#include "json_str.h"

static void test_plain_ascii(void)
{
    char out[16];

    json_str_fold(out, sizeof(out), "hello", 5);
    assert(strcmp(out, "hello") == 0);
}

static void test_unicode_escape(void)
{
    char out[16];

    json_str_fold(out, sizeof(out), "caf\\u00e9", 9);
    assert(strcmp(out, "cafe") == 0);
}

static void test_raw_utf8(void)
{
    char out[16];

    json_str_fold(out, sizeof(out), "d\xc3\xa9j\xc3\xa0 vu", 9);
    assert(strcmp(out, "deja vu") == 0);
}

static void test_escapes(void)
{
    char out[16];

    json_str_fold(out, sizeof(out), "a\\\"b\\\\c\\nd", 10);
    assert(strcmp(out, "a\"b\\c d") == 0);
}

static void test_truncation(void)
{
    char out[6];

    json_str_fold(out, sizeof(out), "abcdefgh", 8);
    assert(strcmp(out, "abcd.") == 0);
}

static void test_oe_ligature(void)
{
    char out[16];

    json_str_fold(out, sizeof(out), "c\xc5\x93ur", 5);
    assert(strcmp(out, "coeur") == 0);
}

int main(void)
{
    test_plain_ascii();
    test_unicode_escape();
    test_raw_utf8();
    test_escapes();
    test_truncation();
    test_oe_ligature();
    printf("test_json_str: OK\n");
    return 0;
}
```

- [ ] **Step 2: Extend `tests/Makefile`** — set `TESTS = test_harness test_json_str` and append:

```make
test_json_str.exe: test_json_str.c ../src/json_str.c
	$(CC) $(CFLAGS) -o $@ $^
```

Run `make -C tests run`. Expected: FAIL (no such file `../src/json_str.c` / missing header).

- [ ] **Step 3: Create `include/json_str.h`**

```c
/*
** EPITECH PROJECT, 2026
** epaper_dashboard
** File description:
** JSON string token extraction with UTF-8 and escape folding to ASCII
*/

#ifndef JSON_STR_H_
    #define JSON_STR_H_

    #include <stddef.h>
    #include <stdint.h>

struct json_out {
    char *dst;
    size_t size;
    size_t pos;
};

struct fold_entry {
    uint32_t cp;
    char const *out;
};

void json_str_fold(char *dst, size_t size, char const *src, size_t len);

#endif /* !JSON_STR_H_ */
```

- [ ] **Step 4: Create `src/json_str.c`**

```c
/*
** EPITECH PROJECT, 2026
** epaper_dashboard
** File description:
** JSON string token extraction with UTF-8 and escape folding to ASCII
*/

#include "json_str.h"

static const struct fold_entry FOLD_TABLE[] = {
    {0xE0, "a"}, {0xE2, "a"}, {0xE4, "a"}, {0xE7, "c"}, {0xE8, "e"},
    {0xE9, "e"}, {0xEA, "e"}, {0xEB, "e"}, {0xEE, "i"}, {0xEF, "i"},
    {0xF4, "o"}, {0xF6, "o"}, {0xF9, "u"}, {0xFB, "u"}, {0xFC, "u"},
    {0xC0, "A"}, {0xC2, "A"}, {0xC7, "C"}, {0xC8, "E"}, {0xC9, "E"},
    {0xCA, "E"}, {0xCB, "E"}, {0xCE, "I"}, {0xCF, "I"}, {0xD4, "O"},
    {0xD9, "U"}, {0xDB, "U"}, {0x153, "oe"}, {0x152, "OE"},
    {0xE6, "ae"}, {0xC6, "AE"}, {0x2019, "'"}, {0x2013, "-"},
    {0x2014, "-"}, {0x2026, "..."}, {0, 0}
};

static int hex_val(char c)
{
    if (c >= '0' && c <= '9')
        return c - '0';
    if ((c | 32) >= 'a' && (c | 32) <= 'f')
        return (c | 32) - 'a' + 10;
    return -1;
}

static size_t decode_hex4(char const *src, uint32_t *cp)
{
    uint32_t value = 0;
    int digit = 0;

    for (size_t i = 0; i < 4; i++) {
        digit = hex_val(src[i]);
        if (digit < 0)
            return 0;
        value = (value << 4) | (uint32_t)digit;
    }
    *cp = value;
    return 4;
}

static size_t decode_escape(char const *src, size_t len, uint32_t *cp)
{
    *cp = '?';
    if (len < 1)
        return 0;
    if (*src == 'u' && len >= 5 && decode_hex4(src + 1, cp) == 4)
        return 5;
    if (*src == 'u')
        return len < 5 ? len : 5;
    if (*src == 'n' || *src == 'r' || *src == 't')
        *cp = ' ';
    if (*src == '"' || *src == '\\' || *src == '/')
        *cp = (uint32_t)*src;
    return 1;
}

static size_t utf8_len(uint8_t lead)
{
    if (lead < 0x80)
        return 1;
    if ((lead & 0xE0) == 0xC0)
        return 2;
    if ((lead & 0xF0) == 0xE0)
        return 3;
    if ((lead & 0xF8) == 0xF0)
        return 4;
    return 0;
}

static size_t decode_utf8(char const *src, size_t len, uint32_t *cp)
{
    size_t need = utf8_len((uint8_t)*src);
    uint32_t value = 0;

    *cp = '?';
    if ((uint8_t)*src < 0x80) {
        *cp = (uint8_t)*src;
        return 1;
    }
    if (need == 0 || need > len)
        return 1;
    value = (uint8_t)*src & (uint32_t)(0xFF >> (need + 1));
    for (size_t i = 1; i < need; i++) {
        if (((uint8_t)src[i] & 0xC0) != 0x80)
            return 1;
        value = (value << 6) | ((uint8_t)src[i] & 0x3F);
    }
    *cp = value;
    return need;
}

static char const *fold_codepoint(uint32_t cp)
{
    static char single[2];

    if (cp >= 0x20 && cp < 0x7F) {
        single[0] = (char)cp;
        single[1] = '\0';
        return single;
    }
    for (size_t i = 0; FOLD_TABLE[i].out != 0; i++) {
        if (FOLD_TABLE[i].cp == cp)
            return FOLD_TABLE[i].out;
    }
    return cp < 0x20 ? " " : "?";
}

static void append_char(struct json_out *out, char c)
{
    if (out->pos + 1 < out->size) {
        out->dst[out->pos] = c;
        out->pos++;
        return;
    }
    if (out->size > 1)
        out->dst[out->size - 2] = '.';
}

static void append_folded(struct json_out *out, char const *s)
{
    for (size_t i = 0; s[i] != '\0'; i++)
        append_char(out, s[i]);
}

void json_str_fold(char *dst, size_t size, char const *src, size_t len)
{
    struct json_out out = {dst, size, 0};
    size_t i = 0;
    uint32_t cp = 0;

    if (size == 0)
        return;
    while (i < len) {
        if (src[i] == '\\')
            i += 1 + decode_escape(src + i + 1, len - i - 1, &cp);
        else
            i += decode_utf8(src + i, len - i, &cp);
        append_folded(&out, fold_codepoint(cp));
    }
    dst[out.pos] = '\0';
}
```

- [ ] **Step 5: Run** `make -C tests run` — Expected: `test_json_str: OK`.

- [ ] **Step 6: Commit** — `git add include/json_str.h src/json_str.c tests` , message `feat: json string folding to ascii with escape and utf-8 support`.

---

### Task 6: `jsmn_util` + `odoo_parse` — response parsing

**Files:**
- Create: `include/jsmn_util.h`, `src/jsmn_util.c`, `include/odoo.h`, `include/odoo_parse.h`, `src/odoo_parse.c`, `tests/test_odoo_parse.c`
- Modify: `tests/Makefile`

**Interfaces:**
- Consumes: `json_str_fold` (Task 5), vendored `jsmn.h` (Task 4).
- Produces:
  - `struct jsmn_ctx { char const *json; size_t len; jsmntok_t const *toks; int count; };`
  - `int jsmn_util_parse(struct jsmn_ctx *ctx, jsmntok_t *toks, int max);` (caller pre-fills `json`+`len`; fills `toks`/`count`; returns count or -1)
  - `int jsmn_tok_eq(struct jsmn_ctx const *ctx, int idx, char const *s);`
  - `int jsmn_next_sibling(struct jsmn_ctx const *ctx, int idx);`
  - `int jsmn_find_key(struct jsmn_ctx const *ctx, char const *key);` (search root object, returns value index or -1)
  - `include/odoo.h`: `ODOO_MAX_TASKS` (12), `ODOO_FETCH_LIMIT` (13), `ODOO_REQ_CAP` (2048), `struct odoo_task { char name[64]; char project[32]; char deadline[11]; char stage[24]; unsigned int priority; };`, `struct odoo_task_list { unsigned int count; unsigned int overflow; struct odoo_task tasks[ODOO_MAX_TASKS]; };`
  - `int odoo_parse_auth(char const *json, size_t len, int *uid);` (0 ok / -1)
  - `int odoo_parse_tasks(char const *json, size_t len, struct odoo_task_list *list);` (0 ok / -1 parse error / -2 Odoo error object; always memsets `list` first)

- [ ] **Step 1: Write the failing test `tests/test_odoo_parse.c`**

```c
/*
** EPITECH PROJECT, 2026
** epaper_dashboard
** File description:
** Unit tests for Odoo JSON-RPC response parsing
*/

#include <assert.h>
#include <stdio.h>
#include <string.h>
#include "odoo_parse.h"

static const char SAMPLE_AUTH[] =
    "{\"jsonrpc\":\"2.0\",\"id\":1,\"result\":42}";
static const char SAMPLE_AUTH_FAIL[] =
    "{\"jsonrpc\":\"2.0\",\"id\":1,\"result\":false}";
static const char SAMPLE_ERROR[] = "{\"jsonrpc\":\"2.0\",\"id\":2,"
    "\"error\":{\"code\":200,\"message\":\"Odoo Server Error\"}}";
static const char SAMPLE_TASKS[] = "{\"jsonrpc\":\"2.0\",\"id\":2,"
    "\"result\":[{\"id\":7,\"name\":\"R\\u00e9parer le module\","
    "\"project_id\":[3,\"Compta\"],\"date_deadline\":\"2026-08-30\","
    "\"stage_id\":[2,\"En cours\"],\"priority\":\"1\"},"
    "{\"id\":8,\"name\":\"Deuxieme tache\",\"project_id\":false,"
    "\"date_deadline\":false,\"stage_id\":[1,\"A faire\"],"
    "\"priority\":\"0\"}]}";

static void test_auth(void)
{
    int uid = 0;

    assert(odoo_parse_auth(SAMPLE_AUTH, strlen(SAMPLE_AUTH), &uid) == 0);
    assert(uid == 42);
    assert(odoo_parse_auth(SAMPLE_AUTH_FAIL, strlen(SAMPLE_AUTH_FAIL),
        &uid) == -1);
    assert(odoo_parse_auth("garbage", 7, &uid) == -1);
}

static void test_tasks_nominal(void)
{
    struct odoo_task_list list;

    assert(odoo_parse_tasks(SAMPLE_TASKS, strlen(SAMPLE_TASKS),
        &list) == 0);
    assert(list.count == 2);
    assert(list.overflow == 0);
    assert(strcmp(list.tasks[0].name, "Reparer le module") == 0);
    assert(strcmp(list.tasks[0].project, "Compta") == 0);
    assert(strcmp(list.tasks[0].deadline, "2026-08-30") == 0);
    assert(strcmp(list.tasks[0].stage, "En cours") == 0);
    assert(list.tasks[0].priority == 1);
}

static void test_tasks_false_fields(void)
{
    struct odoo_task_list list;

    assert(odoo_parse_tasks(SAMPLE_TASKS, strlen(SAMPLE_TASKS),
        &list) == 0);
    assert(strcmp(list.tasks[1].project, "") == 0);
    assert(strcmp(list.tasks[1].deadline, "") == 0);
    assert(strcmp(list.tasks[1].stage, "A faire") == 0);
    assert(list.tasks[1].priority == 0);
}

static void test_error_and_garbage(void)
{
    struct odoo_task_list list;

    assert(odoo_parse_tasks(SAMPLE_ERROR, strlen(SAMPLE_ERROR),
        &list) == -2);
    assert(odoo_parse_tasks("not json at all", 15, &list) == -1);
}

static void build_many(char *dst, size_t size, int n)
{
    size_t pos = 0;

    pos += (size_t)snprintf(dst, size, "{\"result\":[");
    for (int i = 0; i < n; i++)
        pos += (size_t)snprintf(dst + pos, size - pos,
            "%s{\"id\":%d,\"name\":\"T%d\",\"priority\":\"0\"}",
            i > 0 ? "," : "", i, i);
    snprintf(dst + pos, size - pos, "]}");
}

static void test_overflow(void)
{
    static char json[4096];
    struct odoo_task_list list;

    build_many(json, sizeof(json), 13);
    assert(odoo_parse_tasks(json, strlen(json), &list) == 0);
    assert(list.count == 12);
    assert(list.overflow == 1);
    assert(strcmp(list.tasks[11].name, "T11") == 0);
}

int main(void)
{
    test_auth();
    test_tasks_nominal();
    test_tasks_false_fields();
    test_error_and_garbage();
    test_overflow();
    printf("test_odoo_parse: OK\n");
    return 0;
}
```

- [ ] **Step 2: Extend `tests/Makefile`** — `TESTS = test_harness test_json_str test_odoo_parse`, append:

```make
test_odoo_parse.exe: test_odoo_parse.c ../src/odoo_parse.c \
	../src/jsmn_util.c ../src/json_str.c
	$(CC) $(CFLAGS) -o $@ $^
```

Run: expected FAIL (missing files).

- [ ] **Step 3: Create `include/odoo.h`**

```c
/*
** EPITECH PROJECT, 2026
** epaper_dashboard
** File description:
** Odoo task data model shared by parsing, requests, refresh and rendering
*/

#ifndef ODOO_H_
    #define ODOO_H_

#define ODOO_MAX_TASKS 12
#define ODOO_FETCH_LIMIT (ODOO_MAX_TASKS + 1)
#define ODOO_REQ_CAP 2048

struct odoo_task {
    char name[64];
    char project[32];
    char deadline[11];
    char stage[24];
    unsigned int priority;
};

struct odoo_task_list {
    unsigned int count;
    unsigned int overflow;
    struct odoo_task tasks[ODOO_MAX_TASKS];
};

#endif /* !ODOO_H_ */
```

- [ ] **Step 4: Create `include/jsmn_util.h`**

```c
/*
** EPITECH PROJECT, 2026
** epaper_dashboard
** File description:
** Generic helpers over the jsmn token array
*/

#ifndef JSMN_UTIL_H_
    #define JSMN_UTIL_H_

    #include <stddef.h>
    #include "jsmn.h"

struct jsmn_ctx {
    char const *json;
    size_t len;
    jsmntok_t const *toks;
    int count;
};

int jsmn_util_parse(struct jsmn_ctx *ctx, jsmntok_t *toks, int max);
int jsmn_tok_eq(struct jsmn_ctx const *ctx, int idx, char const *s);
int jsmn_next_sibling(struct jsmn_ctx const *ctx, int idx);
int jsmn_find_key(struct jsmn_ctx const *ctx, char const *key);

#endif /* !JSMN_UTIL_H_ */
```

- [ ] **Step 5: Create `src/jsmn_util.c`** (NOTE: `#define JSMN_STATIC` **before** any include — this pulls the jsmn implementation into this one translation unit)

```c
/*
** EPITECH PROJECT, 2026
** epaper_dashboard
** File description:
** Generic helpers over the jsmn token array
*/

#define JSMN_STATIC
#include "jsmn.h"
#include <string.h>
#include "jsmn_util.h"

int jsmn_util_parse(struct jsmn_ctx *ctx, jsmntok_t *toks, int max)
{
    jsmn_parser parser;
    int count = 0;

    jsmn_init(&parser);
    count = jsmn_parse(&parser, ctx->json, ctx->len, toks,
        (unsigned int)max);
    if (count < 1)
        return -1;
    ctx->toks = toks;
    ctx->count = count;
    return count;
}

int jsmn_tok_eq(struct jsmn_ctx const *ctx, int idx, char const *s)
{
    jsmntok_t const *tok = &ctx->toks[idx];
    size_t len = (size_t)(tok->end - tok->start);

    if (tok->type != JSMN_STRING || strlen(s) != len)
        return 0;
    return strncmp(ctx->json + tok->start, s, len) == 0;
}

int jsmn_next_sibling(struct jsmn_ctx const *ctx, int idx)
{
    int end = ctx->toks[idx].end;
    int i = idx + 1;

    while (i < ctx->count && ctx->toks[i].start < end)
        i++;
    return i;
}

int jsmn_find_key(struct jsmn_ctx const *ctx, char const *key)
{
    int i = 1;

    if (ctx->count < 1 || ctx->toks[0].type != JSMN_OBJECT)
        return -1;
    while (i + 1 < ctx->count) {
        if (jsmn_tok_eq(ctx, i, key))
            return i + 1;
        i = jsmn_next_sibling(ctx, i + 1);
    }
    return -1;
}
```

- [ ] **Step 6: Create `include/odoo_parse.h`**

```c
/*
** EPITECH PROJECT, 2026
** epaper_dashboard
** File description:
** Odoo JSON-RPC response parsing into the task data model
*/

#ifndef ODOO_PARSE_H_
    #define ODOO_PARSE_H_

    #include <stddef.h>
    #include "odoo.h"

#define ODOO_MAX_JSON_TOKENS 512

int odoo_parse_auth(char const *json, size_t len, int *uid);
int odoo_parse_tasks(char const *json, size_t len,
    struct odoo_task_list *list);

#endif /* !ODOO_PARSE_H_ */
```

- [ ] **Step 7: Create `src/odoo_parse.c`**

```c
/*
** EPITECH PROJECT, 2026
** epaper_dashboard
** File description:
** Odoo JSON-RPC response parsing into the task data model
*/

#include <stdlib.h>
#include <string.h>
#include "jsmn_util.h"
#include "json_str.h"
#include "odoo_parse.h"

static void copy_tok(struct jsmn_ctx const *ctx, int idx, char *dst,
    size_t size)
{
    jsmntok_t const *tok = &ctx->toks[idx];

    dst[0] = '\0';
    if (idx < ctx->count && tok->type == JSMN_STRING)
        json_str_fold(dst, size, ctx->json + tok->start,
            (size_t)(tok->end - tok->start));
}

static void copy_relation(struct jsmn_ctx const *ctx, int idx, char *dst,
    size_t size)
{
    dst[0] = '\0';
    if (ctx->toks[idx].type == JSMN_ARRAY && ctx->toks[idx].size >= 2)
        copy_tok(ctx, idx + 2, dst, size);
}

static unsigned int priority_of(struct jsmn_ctx const *ctx, int idx)
{
    jsmntok_t const *tok = &ctx->toks[idx];

    if (tok->type == JSMN_STRING || tok->type == JSMN_PRIMITIVE)
        return ctx->json[tok->start] == '1';
    return 0;
}

static void set_task_field(struct jsmn_ctx const *ctx, int key,
    struct odoo_task *task)
{
    int val = key + 1;

    if (jsmn_tok_eq(ctx, key, "name"))
        copy_tok(ctx, val, task->name, sizeof(task->name));
    if (jsmn_tok_eq(ctx, key, "date_deadline"))
        copy_tok(ctx, val, task->deadline, sizeof(task->deadline));
    if (jsmn_tok_eq(ctx, key, "project_id"))
        copy_relation(ctx, val, task->project, sizeof(task->project));
    if (jsmn_tok_eq(ctx, key, "stage_id"))
        copy_relation(ctx, val, task->stage, sizeof(task->stage));
    if (jsmn_tok_eq(ctx, key, "priority"))
        task->priority = priority_of(ctx, val);
}

static void parse_task(struct jsmn_ctx const *ctx, int idx,
    struct odoo_task *task)
{
    int child = idx + 1;
    int pairs = ctx->toks[idx].size;

    for (int n = 0; n < pairs; n++) {
        set_task_field(ctx, child, task);
        child = jsmn_next_sibling(ctx, child + 1);
    }
}

static void parse_task_array(struct jsmn_ctx const *ctx, int idx,
    struct odoo_task_list *list)
{
    int child = idx + 1;
    int total = ctx->toks[idx].size;

    for (int n = 0; n < total; n++) {
        if (n < ODOO_MAX_TASKS)
            parse_task(ctx, child, &list->tasks[n]);
        child = jsmn_next_sibling(ctx, child);
    }
    list->count = total > ODOO_MAX_TASKS ? ODOO_MAX_TASKS
        : (unsigned int)total;
    list->overflow = total > ODOO_MAX_TASKS;
}

int odoo_parse_auth(char const *json, size_t len, int *uid)
{
    static jsmntok_t toks[64];
    struct jsmn_ctx ctx = {json, len, 0, 0};
    int val = 0;

    if (jsmn_util_parse(&ctx, toks, 64) < 0)
        return -1;
    val = jsmn_find_key(&ctx, "result");
    if (val < 0 || val >= ctx.count
        || ctx.toks[val].type != JSMN_PRIMITIVE)
        return -1;
    if (json[ctx.toks[val].start] < '0'
        || json[ctx.toks[val].start] > '9')
        return -1;
    *uid = atoi(json + ctx.toks[val].start);
    return 0;
}

int odoo_parse_tasks(char const *json, size_t len,
    struct odoo_task_list *list)
{
    static jsmntok_t toks[ODOO_MAX_JSON_TOKENS];
    struct jsmn_ctx ctx = {json, len, 0, 0};
    int val = 0;

    memset(list, 0, sizeof(*list));
    if (jsmn_util_parse(&ctx, toks, ODOO_MAX_JSON_TOKENS) < 0)
        return -1;
    if (jsmn_find_key(&ctx, "error") >= 0)
        return -2;
    val = jsmn_find_key(&ctx, "result");
    if (val < 0 || val >= ctx.count || ctx.toks[val].type != JSMN_ARRAY)
        return -1;
    parse_task_array(&ctx, val, list);
    return 0;
}
```

(`odoo_parse_auth` relies on the caller NUL-terminating the buffer for `atoi` — `http_client` guarantees this, and test strings are literals.)

- [ ] **Step 8: Run** `make -C tests run` — Expected: all OK.

- [ ] **Step 9: Commit** — `feat: parse odoo auth and task responses via jsmn`.

---

### Task 7: `odoo_request` — JSON-RPC request builders

**Files:**
- Create: `include/odoo_request.h`, `src/odoo_request.c`, `tests/test_odoo_request.c`
- Modify: `tests/Makefile`

**Interfaces:**
- Consumes: `config.h` macros (`ODOO_DB`, `ODOO_LOGIN`, `ODOO_API_KEY`, `ODOO_TASK_DOMAIN`), `ODOO_FETCH_LIMIT` from `odoo.h`.
- Produces: `int odoo_build_auth(char *dst, size_t size);` and `int odoo_build_tasks(char *dst, size_t size, int uid);` — both return body length, or -1 if truncated.

- [ ] **Step 1: Write the failing test `tests/test_odoo_request.c`**

```c
/*
** EPITECH PROJECT, 2026
** epaper_dashboard
** File description:
** Unit tests for Odoo JSON-RPC request body builders
*/

#include <assert.h>
#include <stdio.h>
#include <string.h>
#include "odoo_request.h"

static void test_auth_body(void)
{
    char body[512];
    int len = odoo_build_auth(body, sizeof(body));

    assert(len > 0);
    assert((size_t)len == strlen(body));
    assert(strstr(body, "\"service\":\"common\"") != 0);
    assert(strstr(body, "\"authenticate\"") != 0);
    assert(strstr(body, "\"testdb\"") != 0);
    assert(strstr(body, "\"tester@test.lan\"") != 0);
    assert(strstr(body, "\"test-key\"") != 0);
}

static void test_tasks_body(void)
{
    char body[2048];
    int len = odoo_build_tasks(body, sizeof(body), 42);

    assert(len > 0);
    assert(strstr(body, "\"execute_kw\"") != 0);
    assert(strstr(body, "\"project.task\"") != 0);
    assert(strstr(body, "\"search_read\"") != 0);
    assert(strstr(body, "[[\"user_ids\",\"in\",[42]]]") != 0);
    assert(strstr(body, "\"limit\":13") != 0);
    assert(strstr(body, "date_deadline asc, priority desc") != 0);
}

static void test_truncation(void)
{
    char body[32];

    assert(odoo_build_auth(body, sizeof(body)) == -1);
    assert(odoo_build_tasks(body, sizeof(body), 1) == -1);
}

int main(void)
{
    test_auth_body();
    test_tasks_body();
    test_truncation();
    printf("test_odoo_request: OK\n");
    return 0;
}
```

- [ ] **Step 2: Extend `tests/Makefile`** — add `test_odoo_request` to `TESTS`, append:

```make
test_odoo_request.exe: test_odoo_request.c ../src/odoo_request.c
	$(CC) $(CFLAGS) -o $@ $^
```

Run: expected FAIL.

- [ ] **Step 3: Create `include/odoo_request.h`**

```c
/*
** EPITECH PROJECT, 2026
** epaper_dashboard
** File description:
** Odoo JSON-RPC request body builders
*/

#ifndef ODOO_REQUEST_H_
    #define ODOO_REQUEST_H_

    #include <stddef.h>

int odoo_build_auth(char *dst, size_t size);
int odoo_build_tasks(char *dst, size_t size, int uid);

#endif /* !ODOO_REQUEST_H_ */
```

- [ ] **Step 4: Create `src/odoo_request.c`**

```c
/*
** EPITECH PROJECT, 2026
** epaper_dashboard
** File description:
** Odoo JSON-RPC request body builders
*/

#include <stdio.h>
#include "config.h"
#include "odoo.h"
#include "odoo_request.h"

static const char AUTH_TEMPLATE[] = "{\"jsonrpc\":\"2.0\","
    "\"method\":\"call\",\"params\":{\"service\":\"common\","
    "\"method\":\"authenticate\",\"args\":[\"%s\",\"%s\",\"%s\",{}]},"
    "\"id\":1}";

static const char TASKS_TEMPLATE[] = "{\"jsonrpc\":\"2.0\","
    "\"method\":\"call\",\"params\":{\"service\":\"object\","
    "\"method\":\"execute_kw\",\"args\":[\"%s\",%d,\"%s\","
    "\"project.task\",\"search_read\",[%s],{\"fields\":[\"name\","
    "\"project_id\",\"date_deadline\",\"stage_id\",\"priority\"],"
    "\"limit\":%d,\"order\":\"date_deadline asc, priority desc\"}]},"
    "\"id\":2}";

int odoo_build_auth(char *dst, size_t size)
{
    int written = snprintf(dst, size, AUTH_TEMPLATE, ODOO_DB, ODOO_LOGIN,
        ODOO_API_KEY);

    if (written < 0 || (size_t)written >= size)
        return -1;
    return written;
}

int odoo_build_tasks(char *dst, size_t size, int uid)
{
    char domain[256];
    int written = snprintf(domain, sizeof(domain), ODOO_TASK_DOMAIN, uid);

    if (written < 0 || (size_t)written >= sizeof(domain))
        return -1;
    written = snprintf(dst, size, TASKS_TEMPLATE, ODOO_DB, uid,
        ODOO_API_KEY, domain, ODOO_FETCH_LIMIT);
    if (written < 0 || (size_t)written >= size)
        return -1;
    return written;
}
```

- [ ] **Step 5: Run** `make -C tests run` — Expected: all OK.
- [ ] **Step 6: Commit** — `feat: build odoo authenticate and search_read request bodies`.

---

### Task 8: `time_fmt` — date/time formatting and deadline classification

**Files:**
- Create: `include/time_fmt.h`, `src/time_fmt.c`, `tests/test_time_fmt.c`
- Modify: `tests/Makefile`

**Interfaces:**
- Consumes: `<time.h>` only.
- Produces:
  - `enum deadline_class { DL_NONE = 0, DL_OVERDUE, DL_SOON, DL_NORMAL };`
  - `void time_fmt_banner(char *dst, size_t size, struct tm const *lt);` → `"mar 26/08"` (French day abbrevs, tm_wday 0=dim)
  - `void time_fmt_hhmm(char *dst, size_t size, struct tm const *lt);` → `"14:35"`
  - `void time_fmt_ddmm(char *dst, size_t size, char const *iso);` → `"30/08"` from `"2026-08-30"`, `"--"` when empty/short
  - `int time_fmt_deadline_class(char const *iso, struct tm const *today);`

- [ ] **Step 1: Write the failing test `tests/test_time_fmt.c`**

```c
/*
** EPITECH PROJECT, 2026
** epaper_dashboard
** File description:
** Unit tests for date formatting and deadline classification
*/

#include <assert.h>
#include <stdio.h>
#include <string.h>
#include <time.h>
#include "time_fmt.h"

static struct tm make_date(int year, int month, int day)
{
    struct tm t = {0};

    t.tm_year = year - 1900;
    t.tm_mon = month - 1;
    t.tm_mday = day;
    t.tm_hour = 12;
    mktime(&t);
    return t;
}

static void test_banner_and_hhmm(void)
{
    struct tm t = make_date(2026, 8, 26);
    char buf[16];

    t.tm_hour = 14;
    t.tm_min = 5;
    time_fmt_banner(buf, sizeof(buf), &t);
    assert(strcmp(buf, "mer 26/08") == 0);
    time_fmt_hhmm(buf, sizeof(buf), &t);
    assert(strcmp(buf, "14:05") == 0);
}

static void test_ddmm(void)
{
    char buf[8];

    time_fmt_ddmm(buf, sizeof(buf), "2026-08-30");
    assert(strcmp(buf, "30/08") == 0);
    time_fmt_ddmm(buf, sizeof(buf), "");
    assert(strcmp(buf, "--") == 0);
}

static void test_deadline_class(void)
{
    struct tm today = make_date(2026, 8, 26);

    assert(time_fmt_deadline_class("2026-08-25", &today) == DL_OVERDUE);
    assert(time_fmt_deadline_class("2026-08-26", &today) == DL_SOON);
    assert(time_fmt_deadline_class("2026-08-27", &today) == DL_SOON);
    assert(time_fmt_deadline_class("2026-08-28", &today) == DL_NORMAL);
    assert(time_fmt_deadline_class("", &today) == DL_NONE);
}

static void test_month_rollover(void)
{
    struct tm today = make_date(2026, 8, 31);

    assert(time_fmt_deadline_class("2026-09-01", &today) == DL_SOON);
    assert(time_fmt_deadline_class("2026-09-02", &today) == DL_NORMAL);
}

int main(void)
{
    test_banner_and_hhmm();
    test_ddmm();
    test_deadline_class();
    test_month_rollover();
    printf("test_time_fmt: OK\n");
    return 0;
}
```

- [ ] **Step 2: Extend `tests/Makefile`** — add `test_time_fmt` to `TESTS`, append:

```make
test_time_fmt.exe: test_time_fmt.c ../src/time_fmt.c
	$(CC) $(CFLAGS) -o $@ $^
```

Run: expected FAIL.

- [ ] **Step 3: Create `include/time_fmt.h`**

```c
/*
** EPITECH PROJECT, 2026
** epaper_dashboard
** File description:
** Date and time formatting helpers plus deadline classification
*/

#ifndef TIME_FMT_H_
    #define TIME_FMT_H_

    #include <stddef.h>
    #include <time.h>

enum deadline_class {
    DL_NONE = 0,
    DL_OVERDUE,
    DL_SOON,
    DL_NORMAL,
};

void time_fmt_banner(char *dst, size_t size, struct tm const *lt);
void time_fmt_hhmm(char *dst, size_t size, struct tm const *lt);
void time_fmt_ddmm(char *dst, size_t size, char const *iso);
int time_fmt_deadline_class(char const *iso, struct tm const *today);

#endif /* !TIME_FMT_H_ */
```

- [ ] **Step 4: Create `src/time_fmt.c`**

```c
/*
** EPITECH PROJECT, 2026
** epaper_dashboard
** File description:
** Date and time formatting helpers plus deadline classification
*/

#include <stdio.h>
#include <string.h>
#include "time_fmt.h"

static const char *DAY_NAMES[7] = {
    "dim", "lun", "mar", "mer", "jeu", "ven", "sam"
};

void time_fmt_banner(char *dst, size_t size, struct tm const *lt)
{
    snprintf(dst, size, "%s %02d/%02d", DAY_NAMES[lt->tm_wday % 7],
        lt->tm_mday, lt->tm_mon + 1);
}

void time_fmt_hhmm(char *dst, size_t size, struct tm const *lt)
{
    snprintf(dst, size, "%02d:%02d", lt->tm_hour, lt->tm_min);
}

void time_fmt_ddmm(char *dst, size_t size, char const *iso)
{
    if (iso == 0 || strlen(iso) < 10) {
        snprintf(dst, size, "--");
        return;
    }
    snprintf(dst, size, "%c%c/%c%c", iso[8], iso[9], iso[5], iso[6]);
}

static void make_iso(char *dst, size_t size, struct tm const *t)
{
    snprintf(dst, size, "%04d-%02d-%02d", t->tm_year + 1900,
        t->tm_mon + 1, t->tm_mday);
}

int time_fmt_deadline_class(char const *iso, struct tm const *today)
{
    char today_iso[11];
    char tomorrow_iso[11];
    struct tm tomorrow = *today;

    if (iso == 0 || iso[0] == '\0')
        return DL_NONE;
    tomorrow.tm_mday++;
    mktime(&tomorrow);
    make_iso(today_iso, sizeof(today_iso), today);
    make_iso(tomorrow_iso, sizeof(tomorrow_iso), &tomorrow);
    if (strncmp(iso, today_iso, 10) < 0)
        return DL_OVERDUE;
    if (strncmp(iso, tomorrow_iso, 10) <= 0)
        return DL_SOON;
    return DL_NORMAL;
}
```

- [ ] **Step 5: Run** `make -C tests run` — Expected: all OK.
- [ ] **Step 6: Commit** — `feat: format banner, clock and deadlines with french day names`.

---

### Task 9: `gfx` — 4bpp framebuffer primitives

**Files:**
- Create: `include/gfx.h`, `src/gfx.c`, `tests/test_gfx.c`
- Modify: `tests/Makefile`

**Interfaces:**
- Consumes: nothing (pure C).
- Produces (also used by `gfx_text`, `dashboard`, `epd_driver`, `main`):
  - `GFX_WIDTH` 800, `GFX_HEIGHT` 480, `GFX_BUFFER_SIZE` (192000)
  - `enum gfx_color { GFX_BLACK = 0x0, GFX_WHITE = 0x1, GFX_YELLOW = 0x2, GFX_RED = 0x3, GFX_BLUE = 0x5, GFX_GREEN = 0x6 };`
  - `struct gfx_rect { int x; int y; int w; int h; };`
  - `struct gfx_style { int x; int y; int color; int scale; };` (consumed by Task 10)
  - `void gfx_fill(uint8_t *fb, int color);` `void gfx_pixel(uint8_t *fb, int x, int y, int color);` `void gfx_fill_rect(uint8_t *fb, struct gfx_rect const *r, int color);` `void gfx_rect(uint8_t *fb, struct gfx_rect const *r, int color);`
  - Pixel packing: GS4_HMSB — byte `(y*800+x)/2`, even x = high nibble. All primitives clip out-of-bounds coordinates silently.

- [ ] **Step 1: Write the failing test `tests/test_gfx.c`**

```c
/*
** EPITECH PROJECT, 2026
** epaper_dashboard
** File description:
** Unit tests for the 4bpp framebuffer primitives
*/

#include <assert.h>
#include <stdio.h>
#include "gfx.h"

static int px(uint8_t const *fb, int x, int y)
{
    size_t idx = ((size_t)y * GFX_WIDTH + (size_t)x) / 2;

    if ((x & 1) == 0)
        return fb[idx] >> 4;
    return fb[idx] & 0x0F;
}

static void test_fill_and_pixel(void)
{
    static uint8_t fb[GFX_BUFFER_SIZE];

    gfx_fill(fb, GFX_WHITE);
    assert(fb[0] == 0x11);
    gfx_pixel(fb, 0, 0, GFX_BLACK);
    assert(fb[0] == 0x01);
    gfx_pixel(fb, 1, 0, GFX_RED);
    assert(fb[0] == 0x03);
    assert(px(fb, 2, 0) == GFX_WHITE);
}

static void test_clipping(void)
{
    static uint8_t fb[GFX_BUFFER_SIZE];
    struct gfx_rect r = {-10, -10, 20, 20};

    gfx_fill(fb, GFX_WHITE);
    gfx_pixel(fb, -1, 0, GFX_BLACK);
    gfx_pixel(fb, GFX_WIDTH, 0, GFX_BLACK);
    gfx_pixel(fb, 0, GFX_HEIGHT, GFX_BLACK);
    gfx_fill_rect(fb, &r, GFX_GREEN);
    assert(px(fb, 0, 0) == GFX_GREEN);
    assert(px(fb, 9, 9) == GFX_GREEN);
    assert(px(fb, 10, 10) == GFX_WHITE);
}

static void test_rect_outline(void)
{
    static uint8_t fb[GFX_BUFFER_SIZE];
    struct gfx_rect r = {10, 10, 5, 5};

    gfx_fill(fb, GFX_WHITE);
    gfx_rect(fb, &r, GFX_BLUE);
    assert(px(fb, 10, 10) == GFX_BLUE);
    assert(px(fb, 14, 14) == GFX_BLUE);
    assert(px(fb, 12, 12) == GFX_WHITE);
}

int main(void)
{
    test_fill_and_pixel();
    test_clipping();
    test_rect_outline();
    printf("test_gfx: OK\n");
    return 0;
}
```

- [ ] **Step 2: Extend `tests/Makefile`** — add `test_gfx` to `TESTS`, append:

```make
test_gfx.exe: test_gfx.c ../src/gfx.c
	$(CC) $(CFLAGS) -o $@ $^
```

Run: expected FAIL.

- [ ] **Step 3: Create `include/gfx.h`**

```c
/*
** EPITECH PROJECT, 2026
** epaper_dashboard
** File description:
** 4bpp GS4_HMSB framebuffer graphics primitives and text rendering
*/

#ifndef GFX_H_
    #define GFX_H_

    #include <stddef.h>
    #include <stdint.h>

#define GFX_WIDTH 800
#define GFX_HEIGHT 480
#define GFX_BUFFER_SIZE (GFX_WIDTH * GFX_HEIGHT / 2)

enum gfx_color {
    GFX_BLACK = 0x0,
    GFX_WHITE = 0x1,
    GFX_YELLOW = 0x2,
    GFX_RED = 0x3,
    GFX_BLUE = 0x5,
    GFX_GREEN = 0x6,
};

struct gfx_rect {
    int x;
    int y;
    int w;
    int h;
};

struct gfx_style {
    int x;
    int y;
    int color;
    int scale;
};

void gfx_fill(uint8_t *fb, int color);
void gfx_pixel(uint8_t *fb, int x, int y, int color);
void gfx_fill_rect(uint8_t *fb, struct gfx_rect const *r, int color);
void gfx_rect(uint8_t *fb, struct gfx_rect const *r, int color);
void gfx_text(uint8_t *fb, struct gfx_style const *st, char const *s);
void gfx_text_centered(uint8_t *fb, struct gfx_style const *st,
    char const *s);
int gfx_text_width(char const *s, int scale);

#endif /* !GFX_H_ */
```

(The three `gfx_text*` prototypes are implemented in Task 10 — declaring them now keeps one header per logical entity.)

- [ ] **Step 4: Create `src/gfx.c`**

```c
/*
** EPITECH PROJECT, 2026
** epaper_dashboard
** File description:
** 4bpp GS4_HMSB framebuffer graphics primitives
*/

#include "gfx.h"

void gfx_fill(uint8_t *fb, int color)
{
    uint8_t byte = (uint8_t)((color << 4) | (color & 0x0F));

    for (size_t i = 0; i < GFX_BUFFER_SIZE; i++)
        fb[i] = byte;
}

void gfx_pixel(uint8_t *fb, int x, int y, int color)
{
    size_t idx = 0;

    if (x < 0 || y < 0 || x >= GFX_WIDTH || y >= GFX_HEIGHT)
        return;
    idx = ((size_t)y * GFX_WIDTH + (size_t)x) / 2;
    if ((x & 1) == 0)
        fb[idx] = (uint8_t)((fb[idx] & 0x0F) | (color << 4));
    else
        fb[idx] = (uint8_t)((fb[idx] & 0xF0) | (color & 0x0F));
}

void gfx_fill_rect(uint8_t *fb, struct gfx_rect const *r, int color)
{
    for (int dy = 0; dy < r->h; dy++) {
        for (int dx = 0; dx < r->w; dx++)
            gfx_pixel(fb, r->x + dx, r->y + dy, color);
    }
}

void gfx_rect(uint8_t *fb, struct gfx_rect const *r, int color)
{
    struct gfx_rect top = {r->x, r->y, r->w, 1};
    struct gfx_rect bottom = {r->x, r->y + r->h - 1, r->w, 1};
    struct gfx_rect left = {r->x, r->y, 1, r->h};
    struct gfx_rect right = {r->x + r->w - 1, r->y, 1, r->h};

    gfx_fill_rect(fb, &top, color);
    gfx_fill_rect(fb, &bottom, color);
    gfx_fill_rect(fb, &left, color);
    gfx_fill_rect(fb, &right, color);
}
```

- [ ] **Step 5: Run** `make -C tests run` — Expected: all OK.
- [ ] **Step 6: Commit** — `feat: 4bpp framebuffer fill, pixel and rectangle primitives`.

---

### Task 10: `gfx_text` — scaled 8×8 font rendering

**Files:**
- Create: `src/gfx_text.c`, `tests/test_gfx_text.c`
- Modify: `tests/Makefile`

**Interfaces:**
- Consumes: `gfx.h` (Task 9 — prototypes already declared there), `lib/font8x8/font8x8_basic.h` (Task 4; included by this `.c` ONLY).
- Produces: implementations of `gfx_text`, `gfx_text_centered`, `gfx_text_width`. Glyphs are 8×8, scaled by pixel duplication; advance = `8 * scale` px per char; font8x8 rows are LSB-leftmost (`(bits >> col) & 1`). If text appears mirrored on the real panel, flip to `(bits >> (7 - col)) & 1` — one-line fix, noted here on purpose.

- [ ] **Step 1: Write the failing test `tests/test_gfx_text.c`**

```c
/*
** EPITECH PROJECT, 2026
** epaper_dashboard
** File description:
** Unit tests for scaled bitmap font text rendering
*/

#include <assert.h>
#include <stdio.h>
#include "gfx.h"

static int px(uint8_t const *fb, int x, int y)
{
    size_t idx = ((size_t)y * GFX_WIDTH + (size_t)x) / 2;

    if ((x & 1) == 0)
        return fb[idx] >> 4;
    return fb[idx] & 0x0F;
}

static int count_color(uint8_t const *fb, struct gfx_rect const *r, int c)
{
    int n = 0;

    for (int y = r->y; y < r->y + r->h; y++) {
        for (int x = r->x; x < r->x + r->w; x++)
            n += px(fb, x, y) == c;
    }
    return n;
}

static void test_glyph_draws_pixels(void)
{
    static uint8_t fb[GFX_BUFFER_SIZE];
    struct gfx_style st = {0, 0, GFX_BLACK, 1};
    struct gfx_rect box = {0, 0, 8, 8};

    gfx_fill(fb, GFX_WHITE);
    gfx_text(fb, &st, "A");
    assert(count_color(fb, &box, GFX_BLACK) > 4);
}

static void test_scale_quadruples_area(void)
{
    static uint8_t fb1[GFX_BUFFER_SIZE];
    static uint8_t fb2[GFX_BUFFER_SIZE];
    struct gfx_style st1 = {0, 0, GFX_BLACK, 1};
    struct gfx_style st2 = {0, 0, GFX_BLACK, 2};
    struct gfx_rect box1 = {0, 0, 8, 8};
    struct gfx_rect box2 = {0, 0, 16, 16};

    gfx_fill(fb1, GFX_WHITE);
    gfx_fill(fb2, GFX_WHITE);
    gfx_text(fb1, &st1, "A");
    gfx_text(fb2, &st2, "A");
    assert(count_color(fb2, &box2, GFX_BLACK)
        == 4 * count_color(fb1, &box1, GFX_BLACK));
}

static void test_width_and_centering(void)
{
    static uint8_t fb[GFX_BUFFER_SIZE];
    struct gfx_style st = {0, 100, GFX_RED, 2};
    struct gfx_rect left = {0, 100, 300, 16};

    assert(gfx_text_width("ab", 2) == 32);
    gfx_fill(fb, GFX_WHITE);
    gfx_text_centered(fb, &st, "ab");
    assert(count_color(fb, &left, GFX_RED) == 0);
}

int main(void)
{
    test_glyph_draws_pixels();
    test_scale_quadruples_area();
    test_width_and_centering();
    printf("test_gfx_text: OK\n");
    return 0;
}
```

- [ ] **Step 2: Extend `tests/Makefile`** — add `test_gfx_text` to `TESTS`, append:

```make
test_gfx_text.exe: test_gfx_text.c ../src/gfx_text.c ../src/gfx.c
	$(CC) $(CFLAGS) -o $@ $^
```

Run: expected FAIL.

- [ ] **Step 3: Create `src/gfx_text.c`**

```c
/*
** EPITECH PROJECT, 2026
** epaper_dashboard
** File description:
** Scaled bitmap text rendering using the public-domain font8x8
*/

#include <string.h>
#include "gfx.h"
#include "font8x8_basic.h"

static void draw_dot(uint8_t *fb, struct gfx_style const *st, int col,
    int row)
{
    struct gfx_rect dot = {st->x + col * st->scale,
        st->y + row * st->scale, st->scale, st->scale};

    gfx_fill_rect(fb, &dot, st->color);
}

static void draw_glyph_row(uint8_t *fb, struct gfx_style const *st,
    uint8_t bits, int row)
{
    for (int col = 0; col < 8; col++) {
        if (((bits >> col) & 1) != 0)
            draw_dot(fb, st, col, row);
    }
}

static void draw_glyph(uint8_t *fb, struct gfx_style const *st, char c)
{
    uint8_t const *rows = (uint8_t const *)font8x8_basic[(uint8_t)c & 0x7F];

    for (int row = 0; row < 8; row++)
        draw_glyph_row(fb, st, rows[row], row);
}

void gfx_text(uint8_t *fb, struct gfx_style const *st, char const *s)
{
    struct gfx_style cur = *st;

    for (size_t i = 0; s[i] != '\0'; i++) {
        draw_glyph(fb, &cur, s[i]);
        cur.x += 8 * cur.scale;
    }
}

int gfx_text_width(char const *s, int scale)
{
    return (int)strlen(s) * 8 * scale;
}

void gfx_text_centered(uint8_t *fb, struct gfx_style const *st,
    char const *s)
{
    struct gfx_style cur = *st;

    cur.x = (GFX_WIDTH - gfx_text_width(s, st->scale)) / 2;
    gfx_text(fb, &cur, s);
}
```

- [ ] **Step 4: Run** `make -C tests run` — Expected: all OK.
- [ ] **Step 5: Commit** — `feat: scaled font8x8 text rendering with centering`.

---

### Task 11: `http_util` — request building and response splitting

**Files:**
- Create: `include/http_util.h`, `src/http_util.c`, `tests/test_http_util.c`
- Modify: `tests/Makefile`

**Interfaces:**
- Consumes: `config.h` (`ODOO_HOST`).
- Produces:
  - `int http_build_request(char *dst, size_t size, char const *path, char const *body);` — full HTTP/1.0 POST request (Host, Content-Type json, Content-Length, Connection: close); returns length or -1.
  - `int http_parse_status(char const *resp, size_t len);` — status code or -1.
  - `long http_body_offset(char const *resp, size_t len);` — offset just past `\r\n\r\n` or -1.

- [ ] **Step 1: Write the failing test `tests/test_http_util.c`**

```c
/*
** EPITECH PROJECT, 2026
** epaper_dashboard
** File description:
** Unit tests for HTTP request building and response splitting
*/

#include <assert.h>
#include <stdio.h>
#include <string.h>
#include "http_util.h"

static void test_build_request(void)
{
    char req[512];
    int len = http_build_request(req, sizeof(req), "/jsonrpc", "{}");

    assert(len > 0);
    assert(strncmp(req, "POST /jsonrpc HTTP/1.0\r\n", 24) == 0);
    assert(strstr(req, "Host: odoo.test.lan\r\n") != 0);
    assert(strstr(req, "Content-Type: application/json\r\n") != 0);
    assert(strstr(req, "Content-Length: 2\r\n") != 0);
    assert(strstr(req, "Connection: close\r\n\r\n{}") != 0);
}

static void test_build_truncation(void)
{
    char req[16];

    assert(http_build_request(req, sizeof(req), "/jsonrpc", "{}") == -1);
}

static void test_parse_status(void)
{
    static const char OK[] = "HTTP/1.0 200 OK\r\n\r\nbody";
    static const char NOTFOUND[] = "HTTP/1.1 404 Not Found\r\n\r\n";

    assert(http_parse_status(OK, strlen(OK)) == 200);
    assert(http_parse_status(NOTFOUND, strlen(NOTFOUND)) == 404);
    assert(http_parse_status("garbage", 7) == -1);
}

static void test_body_offset(void)
{
    static const char RESP[] = "HTTP/1.0 200 OK\r\nA: b\r\n\r\n{\"x\":1}";

    assert(http_body_offset(RESP, strlen(RESP)) == 25);
    assert(strcmp(RESP + 25, "{\"x\":1}") == 0);
    assert(http_body_offset("no separator", 12) == -1);
}

int main(void)
{
    test_build_request();
    test_build_truncation();
    test_parse_status();
    test_body_offset();
    printf("test_http_util: OK\n");
    return 0;
}
```

- [ ] **Step 2: Extend `tests/Makefile`** — add `test_http_util` to `TESTS`, append:

```make
test_http_util.exe: test_http_util.c ../src/http_util.c
	$(CC) $(CFLAGS) -o $@ $^
```

Run: expected FAIL.

- [ ] **Step 3: Create `include/http_util.h`**

```c
/*
** EPITECH PROJECT, 2026
** epaper_dashboard
** File description:
** HTTP/1.0 request building and response splitting helpers
*/

#ifndef HTTP_UTIL_H_
    #define HTTP_UTIL_H_

    #include <stddef.h>

int http_build_request(char *dst, size_t size, char const *path,
    char const *body);
int http_parse_status(char const *resp, size_t len);
long http_body_offset(char const *resp, size_t len);

#endif /* !HTTP_UTIL_H_ */
```

- [ ] **Step 4: Create `src/http_util.c`**

```c
/*
** EPITECH PROJECT, 2026
** epaper_dashboard
** File description:
** HTTP/1.0 request building and response splitting helpers
*/

#include <stdio.h>
#include <string.h>
#include "config.h"
#include "http_util.h"

int http_build_request(char *dst, size_t size, char const *path,
    char const *body)
{
    int written = snprintf(dst, size,
        "POST %s HTTP/1.0\r\n"
        "Host: %s\r\n"
        "Content-Type: application/json\r\n"
        "Content-Length: %u\r\n"
        "Connection: close\r\n\r\n%s",
        path, ODOO_HOST, (unsigned int)strlen(body), body);

    if (written < 0 || (size_t)written >= size)
        return -1;
    return written;
}

int http_parse_status(char const *resp, size_t len)
{
    int status = 0;

    if (len < 12 || strncmp(resp, "HTTP/1.", 7) != 0)
        return -1;
    for (size_t i = 9; i < 12; i++) {
        if (resp[i] < '0' || resp[i] > '9')
            return -1;
        status = status * 10 + (resp[i] - '0');
    }
    return status;
}

long http_body_offset(char const *resp, size_t len)
{
    for (size_t i = 0; i + 3 < len; i++) {
        if (memcmp(resp + i, "\r\n\r\n", 4) == 0)
            return (long)(i + 4);
    }
    return -1;
}
```

- [ ] **Step 5: Run** `make -C tests run` — Expected: all OK.
- [ ] **Step 6: Commit** — `feat: http/1.0 request building and response splitting`.

---

### Task 12: `refresh` — the refresh-decision policy

**Files:**
- Create: `include/refresh.h`, `src/refresh.c`, `tests/test_refresh.c`
- Modify: `tests/Makefile`

**Interfaces:**
- Consumes: `odoo.h`.
- Produces:
  - `struct snapshot { struct odoo_task_list list; unsigned int offline; };` — ALWAYS `memset` a snapshot to 0 before populating (memcmp compares padding too).
  - `struct refresh_times { uint32_t now_s; uint32_t last_refresh_s; unsigned int has_displayed; };`
  - `REFRESH_MIN_GAP_S` (180), `REFRESH_MAX_AGE_S` (86400)
  - `int refresh_needed(struct snapshot const *prev, struct snapshot const *cur, struct refresh_times const *t);`
  - Policy: first-ever display → 1; else `(changed || stale_24h) && spaced_3min`.

- [ ] **Step 1: Write the failing test `tests/test_refresh.c`**

```c
/*
** EPITECH PROJECT, 2026
** epaper_dashboard
** File description:
** Unit tests for the panel refresh decision policy
*/

#include <assert.h>
#include <stdio.h>
#include <string.h>
#include "refresh.h"

static void test_first_display(void)
{
    struct snapshot a;
    struct snapshot b;
    struct refresh_times t = {30, 0, 0};

    memset(&a, 0, sizeof(a));
    memset(&b, 0, sizeof(b));
    assert(refresh_needed(&a, &b, &t) == 1);
}

static void test_unchanged_skips(void)
{
    struct snapshot a;
    struct refresh_times t = {10000, 5000, 1};

    memset(&a, 0, sizeof(a));
    assert(refresh_needed(&a, &a, &t) == 0);
}

static void test_change_triggers_when_spaced(void)
{
    struct snapshot a;
    struct snapshot b;
    struct refresh_times spaced = {1000, 500, 1};
    struct refresh_times close = {600, 500, 1};

    memset(&a, 0, sizeof(a));
    memset(&b, 0, sizeof(b));
    snprintf(b.list.tasks[0].name, sizeof(b.list.tasks[0].name), "X");
    b.list.count = 1;
    assert(refresh_needed(&a, &b, &spaced) == 1);
    assert(refresh_needed(&a, &b, &close) == 0);
}

static void test_daily_health_refresh(void)
{
    struct snapshot a;
    struct refresh_times t = {90000, 100, 1};

    memset(&a, 0, sizeof(a));
    assert(refresh_needed(&a, &a, &t) == 1);
}

static void test_offline_flip_triggers(void)
{
    struct snapshot a;
    struct snapshot b;
    struct refresh_times t = {1000, 500, 1};

    memset(&a, 0, sizeof(a));
    memset(&b, 0, sizeof(b));
    b.offline = 1;
    assert(refresh_needed(&a, &b, &t) == 1);
}

int main(void)
{
    test_first_display();
    test_unchanged_skips();
    test_change_triggers_when_spaced();
    test_daily_health_refresh();
    test_offline_flip_triggers();
    printf("test_refresh: OK\n");
    return 0;
}
```

- [ ] **Step 2: Extend `tests/Makefile`** — add `test_refresh` to `TESTS`, append:

```make
test_refresh.exe: test_refresh.c ../src/refresh.c
	$(CC) $(CFLAGS) -o $@ $^
```

Run: expected FAIL.

- [ ] **Step 3: Create `include/refresh.h`**

```c
/*
** EPITECH PROJECT, 2026
** epaper_dashboard
** File description:
** Panel refresh decision policy: refresh only on change, daily, spaced
*/

#ifndef REFRESH_H_
    #define REFRESH_H_

    #include <stdint.h>
    #include "odoo.h"

#define REFRESH_MIN_GAP_S 180
#define REFRESH_MAX_AGE_S 86400

struct snapshot {
    struct odoo_task_list list;
    unsigned int offline;
};

struct refresh_times {
    uint32_t now_s;
    uint32_t last_refresh_s;
    unsigned int has_displayed;
};

int refresh_needed(struct snapshot const *prev, struct snapshot const *cur,
    struct refresh_times const *t);

#endif /* !REFRESH_H_ */
```

- [ ] **Step 4: Create `src/refresh.c`**

```c
/*
** EPITECH PROJECT, 2026
** epaper_dashboard
** File description:
** Panel refresh decision policy: refresh only on change, daily, spaced
*/

#include <string.h>
#include "refresh.h"

int refresh_needed(struct snapshot const *prev, struct snapshot const *cur,
    struct refresh_times const *t)
{
    int changed = memcmp(prev, cur, sizeof(*prev)) != 0;
    int stale = (t->now_s - t->last_refresh_s) >= REFRESH_MAX_AGE_S;
    int spaced = (t->now_s - t->last_refresh_s) >= REFRESH_MIN_GAP_S;

    if (t->has_displayed == 0)
        return 1;
    return (changed || stale) && spaced;
}
```

- [ ] **Step 5: Run** `make -C tests run` — Expected: all OK.
- [ ] **Step 6: Commit** — `feat: refresh-on-change decision with daily and spacing rules`.

---

### Task 13: `dashboard` — layout and rendering

**Files:**
- Create: `include/dashboard.h`, `src/dashboard.c`, `tests/test_dashboard.c`
- Modify: `tests/Makefile`

**Interfaces:**
- Consumes: `gfx.h`, `time_fmt.h`, `refresh.h` (snapshot).
- Produces:
  - `struct dashboard_data { struct snapshot const *snap; struct tm today; char banner_date[16]; char updated_hhmm[8]; char offline_since[8]; };`
  - `void dashboard_render(uint8_t *fb, struct dashboard_data const *d);`
  - Layout: blue banner 0–59 (title scale 3, date scale 2, "N ouvertes" right-aligned); rows from y=70, 32 px each, up to 12 (red `*` if priority, name ≤24 chars scale 2 at x=32, project ≤9 chars at x=424, deadline DD/MM at x=576 colored by class, stage ≤8 chars at x=664, black separator line); footer y=458 (left slot: red `HORS LIGNE depuis HH:MM` if offline, else `+ d'autres taches` if overflow; right: `mise a jour HH:MM`); empty non-offline list → centered green `Aucune tache ouverte`.

- [ ] **Step 1: Write the failing test `tests/test_dashboard.c`**

```c
/*
** EPITECH PROJECT, 2026
** epaper_dashboard
** File description:
** Unit tests for dashboard layout rendering
*/

#include <assert.h>
#include <stdio.h>
#include <string.h>
#include <time.h>
#include "dashboard.h"

static int px(uint8_t const *fb, int x, int y)
{
    size_t idx = ((size_t)y * GFX_WIDTH + (size_t)x) / 2;

    if ((x & 1) == 0)
        return fb[idx] >> 4;
    return fb[idx] & 0x0F;
}

static int region_has(uint8_t const *fb, struct gfx_rect const *r, int c)
{
    for (int y = r->y; y < r->y + r->h; y++) {
        for (int x = r->x; x < r->x + r->w; x++) {
            if (px(fb, x, y) == c)
                return 1;
        }
    }
    return 0;
}

static void fill_data(struct dashboard_data *d, struct snapshot *snap)
{
    memset(snap, 0, sizeof(*snap));
    memset(d, 0, sizeof(*d));
    d->snap = snap;
    d->today.tm_year = 126;
    d->today.tm_mon = 7;
    d->today.tm_mday = 26;
    snprintf(d->banner_date, sizeof(d->banner_date), "mer 26/08");
    snprintf(d->updated_hhmm, sizeof(d->updated_hhmm), "14:35");
}

static void test_banner_and_rows(void)
{
    static uint8_t fb[GFX_BUFFER_SIZE];
    static struct snapshot snap;
    struct dashboard_data d;
    struct gfx_rect star = {8, 70, 24, 32};
    struct gfx_rect date = {576, 70, 80, 32};

    fill_data(&d, &snap);
    snap.list.count = 1;
    snap.list.tasks[0].priority = 1;
    snprintf(snap.list.tasks[0].name, 64, "Tache urgente");
    snprintf(snap.list.tasks[0].deadline, 11, "2026-08-20");
    dashboard_render(fb, &d);
    assert(px(fb, 5, 5) == GFX_BLUE);
    assert(region_has(fb, &star, GFX_RED));
    assert(region_has(fb, &date, GFX_RED));
}

static void test_empty_state(void)
{
    static uint8_t fb[GFX_BUFFER_SIZE];
    static struct snapshot snap;
    struct dashboard_data d;
    struct gfx_rect middle = {0, 200, GFX_WIDTH, 120};

    fill_data(&d, &snap);
    dashboard_render(fb, &d);
    assert(region_has(fb, &middle, GFX_GREEN));
}

static void test_offline_footer(void)
{
    static uint8_t fb[GFX_BUFFER_SIZE];
    static struct snapshot snap;
    struct dashboard_data d;
    struct gfx_rect footer = {0, 450, GFX_WIDTH, 30};

    fill_data(&d, &snap);
    snap.offline = 1;
    snprintf(d.offline_since, sizeof(d.offline_since), "14:00");
    dashboard_render(fb, &d);
    assert(region_has(fb, &footer, GFX_RED));
}

static void test_deterministic(void)
{
    static uint8_t fb1[GFX_BUFFER_SIZE];
    static uint8_t fb2[GFX_BUFFER_SIZE];
    static struct snapshot snap;
    struct dashboard_data d;

    fill_data(&d, &snap);
    snap.list.count = 1;
    snprintf(snap.list.tasks[0].name, 64, "Stable");
    dashboard_render(fb1, &d);
    dashboard_render(fb2, &d);
    assert(memcmp(fb1, fb2, GFX_BUFFER_SIZE) == 0);
}

int main(void)
{
    test_banner_and_rows();
    test_empty_state();
    test_offline_footer();
    test_deterministic();
    printf("test_dashboard: OK\n");
    return 0;
}
```

- [ ] **Step 2: Extend `tests/Makefile`** — add `test_dashboard` to `TESTS`, append:

```make
test_dashboard.exe: test_dashboard.c ../src/dashboard.c ../src/gfx.c \
	../src/gfx_text.c ../src/time_fmt.c
	$(CC) $(CFLAGS) -o $@ $^
```

Run: expected FAIL.

- [ ] **Step 3: Create `include/dashboard.h`**

```c
/*
** EPITECH PROJECT, 2026
** epaper_dashboard
** File description:
** Dashboard layout rendering of the task snapshot into the framebuffer
*/

#ifndef DASHBOARD_H_
    #define DASHBOARD_H_

    #include <time.h>
    #include "gfx.h"
    #include "refresh.h"

#define DASH_BANNER_H 60
#define DASH_ROWS_TOP 70
#define DASH_ROW_H 32
#define DASH_FOOTER_Y 458

struct dashboard_data {
    struct snapshot const *snap;
    struct tm today;
    char banner_date[16];
    char updated_hhmm[8];
    char offline_since[8];
};

void dashboard_render(uint8_t *fb, struct dashboard_data const *d);

#endif /* !DASHBOARD_H_ */
```

- [ ] **Step 4: Create `src/dashboard.c`**

```c
/*
** EPITECH PROJECT, 2026
** epaper_dashboard
** File description:
** Dashboard layout rendering of the task snapshot into the framebuffer
*/

#include <stdio.h>
#include "dashboard.h"
#include "time_fmt.h"

static void draw_banner(uint8_t *fb, struct dashboard_data const *d)
{
    struct gfx_rect bar = {0, 0, GFX_WIDTH, DASH_BANNER_H};
    struct gfx_style title = {16, 18, GFX_WHITE, 3};
    struct gfx_style date = {360, 22, GFX_WHITE, 2};
    struct gfx_style count = {0, 22, GFX_WHITE, 2};
    char text[24];

    gfx_fill_rect(fb, &bar, GFX_BLUE);
    gfx_text(fb, &title, "MES TACHES");
    gfx_text(fb, &date, d->banner_date);
    snprintf(text, sizeof(text), "%u ouvertes", d->snap->list.count);
    count.x = GFX_WIDTH - 16 - gfx_text_width(text, 2);
    gfx_text(fb, &count, text);
}

static int deadline_color(struct odoo_task const *task,
    struct tm const *today)
{
    int cls = time_fmt_deadline_class(task->deadline, today);

    if (cls == DL_OVERDUE)
        return GFX_RED;
    if (cls == DL_SOON)
        return GFX_BLUE;
    return GFX_BLACK;
}

static void draw_row(uint8_t *fb, struct odoo_task const *task, int y,
    struct tm const *today)
{
    struct gfx_style star = {8, y + 8, GFX_RED, 2};
    struct gfx_style name = {32, y + 8, GFX_BLACK, 2};
    struct gfx_style proj = {424, y + 8, GFX_BLACK, 2};
    struct gfx_style date = {576, y + 8, deadline_color(task, today), 2};
    struct gfx_style stage = {664, y + 8, GFX_BLACK, 2};
    char field[32];

    if (task->priority > 0)
        gfx_text(fb, &star, "*");
    snprintf(field, sizeof(field), "%.24s", task->name);
    gfx_text(fb, &name, field);
    snprintf(field, sizeof(field), "%.9s", task->project);
    gfx_text(fb, &proj, field);
    time_fmt_ddmm(field, sizeof(field), task->deadline);
    gfx_text(fb, &date, field);
    snprintf(field, sizeof(field), "%.8s", task->stage);
    gfx_text(fb, &stage, field);
}

static void draw_rows(uint8_t *fb, struct dashboard_data const *d)
{
    struct gfx_rect sep = {8, 0, GFX_WIDTH - 16, 1};
    int y = DASH_ROWS_TOP;

    for (unsigned int i = 0; i < d->snap->list.count; i++) {
        draw_row(fb, &d->snap->list.tasks[i], y, &d->today);
        sep.y = y + DASH_ROW_H - 1;
        gfx_fill_rect(fb, &sep, GFX_BLACK);
        y += DASH_ROW_H;
    }
}

static void draw_footer(uint8_t *fb, struct dashboard_data const *d)
{
    struct gfx_style left = {8, DASH_FOOTER_Y, GFX_BLACK, 2};
    struct gfx_style right = {0, DASH_FOOTER_Y, GFX_BLACK, 2};
    char text[48];

    snprintf(text, sizeof(text), "mise a jour %s", d->updated_hhmm);
    right.x = GFX_WIDTH - 8 - gfx_text_width(text, 2);
    gfx_text(fb, &right, text);
    if (d->snap->offline != 0) {
        left.color = GFX_RED;
        snprintf(text, sizeof(text), "HORS LIGNE depuis %s",
            d->offline_since);
        gfx_text(fb, &left, text);
        return;
    }
    if (d->snap->list.overflow != 0)
        gfx_text(fb, &left, "+ d'autres taches");
}

static void draw_empty(uint8_t *fb)
{
    struct gfx_style style = {0, 220, GFX_GREEN, 3};

    gfx_text_centered(fb, &style, "Aucune tache ouverte");
}

void dashboard_render(uint8_t *fb, struct dashboard_data const *d)
{
    gfx_fill(fb, GFX_WHITE);
    draw_banner(fb, d);
    if (d->snap->list.count == 0)
        draw_empty(fb);
    else
        draw_rows(fb, d);
    draw_footer(fb, d);
}
```

- [ ] **Step 5: Run** `make -C tests run` — Expected: all OK.
- [ ] **Step 6: Commit** — `feat: render task dashboard layout with status footer`.

---

### Task 14: `epd_io` + `epd_driver` — panel driver port

**Files:**
- Create: `include/epd.h`, `src/epd_io.c`, `src/epd_driver.c`
- Modify: `CMakeLists.txt`

**Interfaces:**
- Consumes: `config.h` (`EPD_CLK_HALF_PERIOD_US`), `gfx.h` (`GFX_BUFFER_SIZE`), Pico SDK gpio/time/watchdog. Port of validated `micropython/main.py` — same pins, same init bytes, same BUSY semantics (BUSY low = busy).
- Produces: `void epd_io_init(void);` `void epd_io_reset(void);` `void epd_io_command(uint8_t cmd);` `void epd_io_data(uint8_t const *data, size_t len);` `int epd_io_wait_idle(uint32_t timeout_ms);` `int epd_init(void);` `int epd_display(uint8_t const *fb);` `void epd_sleep(void);` — per-refresh flow used by main: `epd_init()` → `epd_display(fb)` → `epd_sleep()` (always, even on failure).

- [ ] **Step 1: Create `include/epd.h`**

```c
/*
** EPITECH PROJECT, 2026
** epaper_dashboard
** File description:
** Waveshare 7.3 inch e-Paper HAT (E) Spectra 6 driver over paced bit-bang
*/

#ifndef EPD_H_
    #define EPD_H_

    #include <stddef.h>
    #include <stdint.h>

    #ifndef EPD_CLK_HALF_PERIOD_US
        #define EPD_CLK_HALF_PERIOD_US 1
    #endif

#define EPD_RST_PIN 12
#define EPD_DC_PIN 8
#define EPD_CS_PIN 9
#define EPD_BUSY_PIN 13
#define EPD_CLK_PIN 10
#define EPD_DIN_PIN 11

struct epd_cmd {
    uint8_t cmd;
    uint8_t len;
    uint8_t data[6];
};

void epd_io_init(void);
void epd_io_reset(void);
void epd_io_command(uint8_t cmd);
void epd_io_data(uint8_t const *data, size_t len);
int epd_io_wait_idle(uint32_t timeout_ms);
int epd_init(void);
int epd_display(uint8_t const *fb);
void epd_sleep(void);

#endif /* !EPD_H_ */
```

- [ ] **Step 2: Create `src/epd_io.c`**

```c
/*
** EPITECH PROJECT, 2026
** epaper_dashboard
** File description:
** Paced bit-bang SPI transport for the e-paper panel (mode 0, MSB first)
*/

#include "pico/stdlib.h"
#include "hardware/gpio.h"
#include "hardware/watchdog.h"
#include "config.h"
#include "epd.h"

void epd_io_init(void)
{
    gpio_init(EPD_RST_PIN);
    gpio_init(EPD_DC_PIN);
    gpio_init(EPD_CS_PIN);
    gpio_init(EPD_CLK_PIN);
    gpio_init(EPD_DIN_PIN);
    gpio_init(EPD_BUSY_PIN);
    gpio_set_dir(EPD_RST_PIN, GPIO_OUT);
    gpio_set_dir(EPD_DC_PIN, GPIO_OUT);
    gpio_set_dir(EPD_CS_PIN, GPIO_OUT);
    gpio_set_dir(EPD_CLK_PIN, GPIO_OUT);
    gpio_set_dir(EPD_DIN_PIN, GPIO_OUT);
    gpio_set_dir(EPD_BUSY_PIN, GPIO_IN);
    gpio_pull_up(EPD_BUSY_PIN);
    gpio_put(EPD_CS_PIN, 1);
    gpio_put(EPD_CLK_PIN, 0);
}

void epd_io_reset(void)
{
    gpio_put(EPD_RST_PIN, 1);
    sleep_ms(20);
    gpio_put(EPD_RST_PIN, 0);
    sleep_ms(2);
    gpio_put(EPD_RST_PIN, 1);
    sleep_ms(20);
}

static void tx_byte(uint8_t byte)
{
    for (int bit = 7; bit >= 0; bit--) {
        gpio_put(EPD_DIN_PIN, (byte >> bit) & 1);
        busy_wait_us(EPD_CLK_HALF_PERIOD_US);
        gpio_put(EPD_CLK_PIN, 1);
        busy_wait_us(EPD_CLK_HALF_PERIOD_US);
        gpio_put(EPD_CLK_PIN, 0);
    }
}

void epd_io_command(uint8_t cmd)
{
    gpio_put(EPD_DC_PIN, 0);
    gpio_put(EPD_CS_PIN, 0);
    tx_byte(cmd);
    gpio_put(EPD_CS_PIN, 1);
}

void epd_io_data(uint8_t const *data, size_t len)
{
    gpio_put(EPD_DC_PIN, 1);
    gpio_put(EPD_CS_PIN, 0);
    for (size_t i = 0; i < len; i++) {
        tx_byte(data[i]);
        if ((i & 0xFF) == 0)
            watchdog_update();
    }
    gpio_put(EPD_CS_PIN, 1);
}

int epd_io_wait_idle(uint32_t timeout_ms)
{
    absolute_time_t deadline = make_timeout_time_ms(timeout_ms);

    sleep_ms(30);
    while (gpio_get(EPD_BUSY_PIN) == 0) {
        if (absolute_time_diff_us(get_absolute_time(), deadline) < 0)
            return -1;
        watchdog_update();
        sleep_ms(10);
    }
    return 0;
}
```

- [ ] **Step 3: Create `src/epd_driver.c`**

```c
/*
** EPITECH PROJECT, 2026
** epaper_dashboard
** File description:
** Panel init sequence, refresh cycle and deep sleep (port of main.py)
*/

#include "pico/stdlib.h"
#include "hardware/gpio.h"
#include "hardware/watchdog.h"
#include "epd.h"
#include "gfx.h"

static const struct epd_cmd INIT_SEQUENCE[] = {
    {0xAA, 6, {0x49, 0x55, 0x20, 0x08, 0x09, 0x18}},
    {0x01, 1, {0x3F, 0, 0, 0, 0, 0}},
    {0x00, 2, {0x5F, 0x69, 0, 0, 0, 0}},
    {0x03, 4, {0x00, 0x54, 0x00, 0x44, 0, 0}},
    {0x05, 4, {0x40, 0x1F, 0x1F, 0x2C, 0, 0}},
    {0x06, 4, {0x6F, 0x1F, 0x17, 0x49, 0, 0}},
    {0x08, 4, {0x6F, 0x1F, 0x1F, 0x22, 0, 0}},
    {0x30, 1, {0x03, 0, 0, 0, 0, 0}},
    {0x50, 1, {0x3F, 0, 0, 0, 0, 0}},
    {0x60, 2, {0x02, 0x00, 0, 0, 0, 0}},
    {0x61, 4, {0x03, 0x20, 0x01, 0xE0, 0, 0}},
    {0x84, 1, {0x01, 0, 0, 0, 0, 0}},
    {0xE3, 1, {0x2F, 0, 0, 0, 0, 0}},
};

static void send_init_sequence(void)
{
    size_t total = sizeof(INIT_SEQUENCE) / sizeof(INIT_SEQUENCE[0]);

    for (size_t i = 0; i < total; i++) {
        epd_io_command(INIT_SEQUENCE[i].cmd);
        epd_io_data(INIT_SEQUENCE[i].data, INIT_SEQUENCE[i].len);
    }
}

static int power_on_reacts(void)
{
    absolute_time_t deadline = make_timeout_time_ms(3000);

    epd_io_command(0x04);
    while (absolute_time_diff_us(get_absolute_time(), deadline) > 0) {
        if (gpio_get(EPD_BUSY_PIN) == 0)
            return epd_io_wait_idle(60000);
        watchdog_update();
        sleep_ms(2);
    }
    return -1;
}

int epd_init(void)
{
    for (int attempt = 0; attempt < 3; attempt++) {
        epd_io_reset();
        epd_io_wait_idle(5000);
        send_init_sequence();
        if (power_on_reacts() == 0)
            return 0;
        sleep_ms(200);
    }
    return -1;
}

static int turn_on_display(void)
{
    uint8_t zero = 0x00;

    epd_io_command(0x04);
    if (epd_io_wait_idle(60000) != 0)
        return -1;
    epd_io_command(0x12);
    epd_io_data(&zero, 1);
    if (epd_io_wait_idle(60000) != 0)
        return -1;
    epd_io_command(0x02);
    epd_io_data(&zero, 1);
    return epd_io_wait_idle(60000);
}

int epd_display(uint8_t const *fb)
{
    epd_io_command(0x10);
    epd_io_data(fb, GFX_BUFFER_SIZE);
    return turn_on_display();
}

void epd_sleep(void)
{
    uint8_t code = 0xA5;

    epd_io_command(0x07);
    epd_io_data(&code, 1);
    sleep_ms(20);
}
```

- [ ] **Step 4: Extend `CMakeLists.txt`** — in `add_executable`, the source list becomes:

```cmake
add_executable(epaper_dashboard
    src/main.c
    src/epd_io.c
    src/epd_driver.c
    src/gfx.c
    src/gfx_text.c
    src/json_str.c
    src/jsmn_util.c
    src/odoo_parse.c
    src/odoo_request.c
    src/time_fmt.c
    src/http_util.c
    src/refresh.c
    src/dashboard.c
)
```

and `target_link_libraries` gains `hardware_watchdog`. These files reference `config.h` — add the config gate right after `project(...)`:

```cmake
if(NOT EXISTS ${CMAKE_CURRENT_LIST_DIR}/include/config.h)
    message(FATAL_ERROR
        "include/config.h missing: copy config.h.example there first")
endif()
```

Then create a local build config: `cp config.h.example include/config.h` (dummy values are fine for compiling; verify `git status` shows it untracked).

- [ ] **Step 5: Build** — `cmake -S . -B build -G Ninja && cmake --build build`. Expected: `.uf2` produced, no warnings in our files.

- [ ] **Step 6: Commit** — `feat: port validated e-paper driver to paced bit-bang C` (config.h must NOT be in the commit).

---

### Task 15: WiFi bring-up

**Files:**
- Create: `lwipopts.h`, `include/net_wifi.h`, `src/net_wifi.c`, `include/sys_idle.h`, `src/sys_idle.c`
- Modify: `CMakeLists.txt`, `src/main.c` (temporary wifi-demo main, replaced in Task 19)

**Interfaces:**
- Consumes: `config.h` (`WIFI_SSID`, `WIFI_PASSWORD`, `WIFI_COUNTRY`), Task 1 SDK.
- Produces: `int net_wifi_init(void);` `int net_wifi_connect(void);` (blocking ≤30 s, watchdog-fed, -1 on fail) `int net_wifi_up(void);` `void net_wifi_led(int on);` `void sys_idle_ms(uint32_t ms);` (sleep slices + `cyw43_arch_poll` + `watchdog_update`); `lwipopts.h` used by all later network tasks.

- [ ] **Step 1: Create `lwipopts.h`** — clone examples and merge (Bash):

```bash
git clone --depth 1 https://github.com/raspberrypi/pico-examples.git \
  "$TMPDIR_SCRATCH/pico-examples" 2>/dev/null || true
cp "$TMPDIR_SCRATCH/pico-examples/pico_w/wifi/lwipopts_examples_common.h" lwipopts.h
```

(Use the session scratchpad directory for the clone.) Then edit `lwipopts.h`: change its include guard to `LWIPOPTS_H_` if needed, and append **before** the final `#endif`:

```c
/* project additions: sntp (Task 16) and altcp tls (Task 17) land here */
```

Keep the file otherwise verbatim (it is derived config, style-exempt like vendored code, but keep LF endings).

- [ ] **Step 2: Create `include/sys_idle.h`** and **`src/sys_idle.c`**

```c
/*
** EPITECH PROJECT, 2026
** epaper_dashboard
** File description:
** Watchdog-fed idle wait that keeps the wifi driver polled
*/

#ifndef SYS_IDLE_H_
    #define SYS_IDLE_H_

    #include <stdint.h>

void sys_idle_ms(uint32_t ms);

#endif /* !SYS_IDLE_H_ */
```

```c
/*
** EPITECH PROJECT, 2026
** epaper_dashboard
** File description:
** Watchdog-fed idle wait that keeps the wifi driver polled
*/

#include "pico/stdlib.h"
#include "pico/cyw43_arch.h"
#include "hardware/watchdog.h"
#include "sys_idle.h"

void sys_idle_ms(uint32_t ms)
{
    absolute_time_t deadline = make_timeout_time_ms(ms);

    while (absolute_time_diff_us(get_absolute_time(), deadline) > 0) {
        cyw43_arch_poll();
        watchdog_update();
        sleep_ms(10);
    }
}
```

- [ ] **Step 3: Create `include/net_wifi.h`** and **`src/net_wifi.c`**

```c
/*
** EPITECH PROJECT, 2026
** epaper_dashboard
** File description:
** WiFi station bring-up, reconnection and status
*/

#ifndef NET_WIFI_H_
    #define NET_WIFI_H_

int net_wifi_init(void);
int net_wifi_connect(void);
int net_wifi_up(void);
void net_wifi_led(int on);

#endif /* !NET_WIFI_H_ */
```

```c
/*
** EPITECH PROJECT, 2026
** epaper_dashboard
** File description:
** WiFi station bring-up, reconnection and status
*/

#include "pico/stdlib.h"
#include "pico/cyw43_arch.h"
#include "hardware/watchdog.h"
#include "config.h"
#include "net_wifi.h"

int net_wifi_init(void)
{
    if (cyw43_arch_init_with_country(WIFI_COUNTRY) != 0)
        return -1;
    cyw43_arch_enable_sta_mode();
    return 0;
}

int net_wifi_connect(void)
{
    absolute_time_t deadline = make_timeout_time_ms(30000);
    int status = 0;

    if (cyw43_arch_wifi_connect_async(WIFI_SSID, WIFI_PASSWORD,
        CYW43_AUTH_WPA2_AES_PSK) != 0)
        return -1;
    while (absolute_time_diff_us(get_absolute_time(), deadline) > 0) {
        cyw43_arch_poll();
        watchdog_update();
        status = cyw43_tcpip_link_status(&cyw43_state, CYW43_ITF_STA);
        if (status == CYW43_LINK_UP)
            return 0;
        if (status < 0)
            return -1;
        sleep_ms(50);
    }
    return -1;
}

int net_wifi_up(void)
{
    return cyw43_tcpip_link_status(&cyw43_state, CYW43_ITF_STA)
        == CYW43_LINK_UP;
}

void net_wifi_led(int on)
{
    cyw43_arch_gpio_put(CYW43_WL_GPIO_LED_PIN, on != 0);
}
```

- [ ] **Step 4: Replace `src/main.c` with the wifi demo** (temporary — Task 19 replaces it):

```c
/*
** EPITECH PROJECT, 2026
** epaper_dashboard
** File description:
** Entry point (wifi bring-up demo, replaced by the real superloop later)
*/

#include <stdio.h>
#include "pico/stdlib.h"
#include "pico/cyw43_arch.h"
#include "hardware/watchdog.h"
#include "net_wifi.h"
#include "sys_idle.h"

int main(void)
{
    stdio_init_all();
    watchdog_enable(8000, 1);
    if (net_wifi_init() != 0) {
        printf("wifi: init failed\n");
        return 1;
    }
    while (net_wifi_connect() != 0)
        printf("wifi: connect failed, retrying\n");
    printf("wifi: connected\n");
    for (;;) {
        net_wifi_led(1);
        sys_idle_ms(500);
        net_wifi_led(0);
        sys_idle_ms(500);
    }
    return 0;
}
```

- [ ] **Step 5: Extend `CMakeLists.txt`** — add `src/net_wifi.c` and `src/sys_idle.c` to the source list; change `target_link_libraries` to:

```cmake
target_link_libraries(epaper_dashboard
    pico_stdlib
    pico_cyw43_arch_lwip_poll
    hardware_watchdog
)
```

- [ ] **Step 6: Build** — expected: `.uf2` builds.
- [ ] **Step 7 [HW]:** ask user to flash; serial should show `wifi: connected` and the onboard LED blinks. Continue regardless.
- [ ] **Step 8: Commit** — `feat: wifi station bring-up with watchdog-fed polling`.

---

### Task 16: SNTP time sync

**Files:**
- Create: `include/net_time.h`, `src/net_time.c`
- Modify: `lwipopts.h`, `CMakeLists.txt`, `src/main.c` (add time log line to demo main)

**Interfaces:**
- Consumes: lwIP SNTP app, `pico_aon_timer`, `config.h` (`NTP_SERVER`, `TZ_OFFSET_MIN`).
- Produces: `void net_time_init(void);` `int net_time_synced(void);` `void net_time_local(struct tm *out);` `void net_time_sntp_set(unsigned int sec);` (called by lwIP via macro — do not call manually).

- [ ] **Step 1: Append the SNTP block to `lwipopts.h`** (before final `#endif`):

```c
#define SNTP_SERVER_DNS 1
#define SNTP_STARTUP_DELAY 0
extern void net_time_sntp_set(unsigned int sec);
#define SNTP_SET_SYSTEM_TIME(sec) net_time_sntp_set(sec)
```

- [ ] **Step 2: Create `include/net_time.h`** and **`src/net_time.c`**

```c
/*
** EPITECH PROJECT, 2026
** epaper_dashboard
** File description:
** SNTP time synchronisation backed by the always-on timer
*/

#ifndef NET_TIME_H_
    #define NET_TIME_H_

    #include <time.h>

void net_time_init(void);
int net_time_synced(void);
void net_time_local(struct tm *out);
void net_time_sntp_set(unsigned int sec);

#endif /* !NET_TIME_H_ */
```

```c
/*
** EPITECH PROJECT, 2026
** epaper_dashboard
** File description:
** SNTP time synchronisation backed by the always-on timer
*/

#include "pico/aon_timer.h"
#include "lwip/apps/sntp.h"
#include "config.h"
#include "net_time.h"

void net_time_init(void)
{
    sntp_setoperatingmode(SNTP_OPMODE_POLL);
    sntp_setservername(0, NTP_SERVER);
    sntp_init();
}

void net_time_sntp_set(unsigned int sec)
{
    struct timespec ts = {(time_t)sec, 0};

    if (aon_timer_is_running())
        aon_timer_set_time(&ts);
    else
        aon_timer_start(&ts);
}

int net_time_synced(void)
{
    return aon_timer_is_running() ? 1 : 0;
}

void net_time_local(struct tm *out)
{
    struct timespec ts = {0, 0};
    time_t local = 0;

    aon_timer_get_time(&ts);
    local = ts.tv_sec + TZ_OFFSET_MIN * 60;
    gmtime_r(&local, out);
}
```

- [ ] **Step 3: Wire into the demo main** — after `wifi: connected`, add:

```c
    net_time_init();
    while (net_time_synced() == 0)
        sys_idle_ms(500);
    printf("time: synced\n");
```

(with `#include "net_time.h"` on top; keep `main` ≤ 20 lines by removing the LED blink loop body to a single `sys_idle_ms(1000);` if needed).

- [ ] **Step 4: Extend `CMakeLists.txt`** — add `src/net_time.c` to sources; add `pico_lwip_sntp` and `pico_aon_timer` to `target_link_libraries`.
- [ ] **Step 5: Build** — expected `.uf2` builds. If `pico_aon_timer` is unknown in the chosen SDK tag, use `hardware_rtc`-equivalent `aon_timer` naming from that SDK's docs (`ls $PICO_SDK_PATH/src/common | grep -i aon`) and adapt.
- [ ] **Step 6 [HW]:** user flash → serial shows `time: synced`. Continue regardless.
- [ ] **Step 7: Commit** — `feat: sntp time sync stored in the always-on timer`.

---

### Task 17: TLS HTTP client

**Files:**
- Create: `mbedtls_config.h`, `include/http_client.h`, `src/http_conn.c`, `src/http_client.c`
- Modify: `lwipopts.h`, `CMakeLists.txt`

**Interfaces:**
- Consumes: `http_util` (Task 11), lwIP altcp_tls + mbedTLS, `config.h` (`ODOO_HOST`, `ODOO_PORT`, optional `ODOO_CA_CERT`).
- Produces:
  - `struct http_ctx { struct altcp_pcb *pcb; char const *request; size_t request_len; char *resp; size_t resp_cap; size_t resp_len; ip_addr_t addr; int phase; };` (phase: 0 dns-wait, 1 resolved, 2 sent, 3 done, <0 error)
  - `struct http_response { int status; char const *body; size_t body_len; };`
  - `int http_conn_resolve(struct http_ctx *ctx);` `int http_conn_open(struct http_ctx *ctx, struct altcp_tls_config *tls);` `int http_conn_wait(struct http_ctx *ctx, int target, uint32_t timeout_ms);` `void http_conn_close(struct http_ctx *ctx);`
  - `int http_post_json(char const *path, char const *body, struct http_response *out);` — 0 ok / -1 network / -2 bad status or malformed. Body points into a static buffer (valid until next call) and is NUL-terminated.
  - `HTTP_RESP_CAP` 16384, `HTTP_REQ_CAP` 4096.

- [ ] **Step 1: Copy `mbedtls_config.h`** from the examples clone (Bash):

```bash
cp "$TMPDIR_SCRATCH/pico-examples/pico_w/wifi/tls_client/mbedtls_config.h" mbedtls_config.h
grep -c MBEDTLS_SSL_CLI_C mbedtls_config.h
```

Expected: `1`. Verify `MBEDTLS_HAVE_TIME` is NOT defined in it (if it is, remove it — cert time validity is deliberately unchecked, see Global Constraints deviation 1). Keep the file otherwise verbatim.

- [ ] **Step 2: Append the ALTCP/TLS block to `lwipopts.h`** (before final `#endif`):

```c
#define LWIP_ALTCP 1
#define LWIP_ALTCP_TLS 1
#define LWIP_ALTCP_TLS_MBEDTLS 1
#define MEM_SIZE 8000
```

(If the copied file already defines `MEM_SIZE`, replace its value with 8000 instead of redefining.)

- [ ] **Step 3: Create `include/http_client.h`**

```c
/*
** EPITECH PROJECT, 2026
** epaper_dashboard
** File description:
** One-shot HTTPS POST client over lwIP altcp_tls
*/

#ifndef HTTP_CLIENT_H_
    #define HTTP_CLIENT_H_

    #include <stddef.h>
    #include "lwip/altcp.h"
    #include "lwip/altcp_tls.h"
    #include "lwip/ip_addr.h"

#define HTTP_RESP_CAP 16384
#define HTTP_REQ_CAP 4096

struct http_ctx {
    struct altcp_pcb *pcb;
    char const *request;
    size_t request_len;
    char *resp;
    size_t resp_cap;
    size_t resp_len;
    ip_addr_t addr;
    int phase;
};

struct http_response {
    int status;
    char const *body;
    size_t body_len;
};

int http_conn_resolve(struct http_ctx *ctx);
int http_conn_open(struct http_ctx *ctx, struct altcp_tls_config *tls);
int http_conn_wait(struct http_ctx *ctx, int target, uint32_t timeout_ms);
void http_conn_close(struct http_ctx *ctx);
int http_post_json(char const *path, char const *body,
    struct http_response *out);

#endif /* !HTTP_CLIENT_H_ */
```

- [ ] **Step 4: Create `src/http_conn.c`**

```c
/*
** EPITECH PROJECT, 2026
** epaper_dashboard
** File description:
** Connection lifecycle and lwIP callbacks for the HTTPS client
*/

#include "pico/stdlib.h"
#include "pico/cyw43_arch.h"
#include "hardware/watchdog.h"
#include "lwip/dns.h"
#include "lwip/pbuf.h"
#include "mbedtls/ssl.h"
#include "config.h"
#include "http_client.h"

static void cb_dns(char const *name, ip_addr_t const *addr, void *arg)
{
    struct http_ctx *ctx = arg;

    (void)name;
    if (addr == 0) {
        ctx->phase = -1;
        return;
    }
    ctx->addr = *addr;
    ctx->phase = 1;
}

static err_t cb_connected(void *arg, struct altcp_pcb *pcb, err_t err)
{
    struct http_ctx *ctx = arg;

    if (err != ERR_OK) {
        ctx->phase = -2;
        return ERR_OK;
    }
    altcp_write(pcb, ctx->request, (u16_t)ctx->request_len, 0);
    altcp_output(pcb);
    ctx->phase = 2;
    return ERR_OK;
}

static err_t cb_recv(void *arg, struct altcp_pcb *pcb, struct pbuf *p,
    err_t err)
{
    struct http_ctx *ctx = arg;
    u16_t room = (u16_t)(ctx->resp_cap - ctx->resp_len - 1);
    u16_t copied = 0;

    (void)err;
    if (p == 0) {
        ctx->phase = 3;
        return ERR_OK;
    }
    copied = pbuf_copy_partial(p, ctx->resp + ctx->resp_len, room, 0);
    ctx->resp_len += copied;
    if (copied < p->tot_len)
        ctx->phase = -3;
    altcp_recved(pcb, p->tot_len);
    pbuf_free(p);
    return ERR_OK;
}

static void cb_err(void *arg, err_t err)
{
    struct http_ctx *ctx = arg;

    (void)err;
    ctx->pcb = 0;
    if (ctx->phase != 3)
        ctx->phase = -4;
}

int http_conn_resolve(struct http_ctx *ctx)
{
    err_t err = dns_gethostbyname(ODOO_HOST, &ctx->addr, cb_dns, ctx);

    if (err == ERR_OK) {
        ctx->phase = 1;
        return 0;
    }
    if (err != ERR_INPROGRESS)
        return -1;
    return http_conn_wait(ctx, 1, 10000);
}

int http_conn_open(struct http_ctx *ctx, struct altcp_tls_config *tls)
{
    ctx->pcb = altcp_tls_new(tls, IPADDR_TYPE_V4);
    if (ctx->pcb == 0)
        return -1;
    mbedtls_ssl_set_hostname(altcp_tls_context(ctx->pcb), ODOO_HOST);
    altcp_arg(ctx->pcb, ctx);
    altcp_err(ctx->pcb, cb_err);
    altcp_recv(ctx->pcb, cb_recv);
    if (altcp_connect(ctx->pcb, &ctx->addr, ODOO_PORT, cb_connected)
        != ERR_OK)
        return -1;
    return 0;
}

int http_conn_wait(struct http_ctx *ctx, int target, uint32_t timeout_ms)
{
    absolute_time_t deadline = make_timeout_time_ms(timeout_ms);

    while (ctx->phase >= 0 && ctx->phase < target) {
        if (absolute_time_diff_us(get_absolute_time(), deadline) < 0)
            return -1;
        cyw43_arch_poll();
        watchdog_update();
        sleep_ms(5);
    }
    return ctx->phase >= target ? 0 : -1;
}

void http_conn_close(struct http_ctx *ctx)
{
    if (ctx->pcb == 0)
        return;
    altcp_arg(ctx->pcb, 0);
    if (altcp_close(ctx->pcb) != ERR_OK)
        altcp_abort(ctx->pcb);
    ctx->pcb = 0;
}
```

- [ ] **Step 5: Create `src/http_client.c`**

```c
/*
** EPITECH PROJECT, 2026
** epaper_dashboard
** File description:
** One-shot HTTPS POST client over lwIP altcp_tls
*/

#include <string.h>
#include "config.h"
#include "http_client.h"
#include "http_util.h"

#ifdef ODOO_CA_CERT
    #define ODOO_CA_CERT_PTR ((u8_t const *)ODOO_CA_CERT)
    #define ODOO_CA_CERT_LEN (sizeof(ODOO_CA_CERT))
#else
    #define ODOO_CA_CERT_PTR 0
    #define ODOO_CA_CERT_LEN 0
#endif

static struct altcp_tls_config *make_tls_config(void)
{
    return altcp_tls_create_config_client(ODOO_CA_CERT_PTR,
        ODOO_CA_CERT_LEN);
}

static int parse_response(struct http_ctx *ctx, struct http_response *out)
{
    long body_off = 0;

    ctx->resp[ctx->resp_len] = '\0';
    body_off = http_body_offset(ctx->resp, ctx->resp_len);
    out->status = http_parse_status(ctx->resp, ctx->resp_len);
    if (out->status != 200 || body_off < 0)
        return -2;
    out->body = ctx->resp + body_off;
    out->body_len = ctx->resp_len - (size_t)body_off;
    return 0;
}

static int finish(struct http_ctx *ctx, struct altcp_tls_config *tls,
    int code)
{
    http_conn_close(ctx);
    if (tls != 0)
        altcp_tls_free_config(tls);
    return code;
}

int http_post_json(char const *path, char const *body,
    struct http_response *out)
{
    static char resp[HTTP_RESP_CAP];
    static char req[HTTP_REQ_CAP];
    struct http_ctx ctx = {0, req, 0, resp, HTTP_RESP_CAP, 0, {0}, 0};
    struct altcp_tls_config *tls = make_tls_config();
    int built = http_build_request(req, sizeof(req), path, body);

    if (tls == 0 || built < 0)
        return finish(&ctx, tls, -1);
    ctx.request_len = (size_t)built;
    if (http_conn_resolve(&ctx) != 0 || http_conn_open(&ctx, tls) != 0)
        return finish(&ctx, tls, -1);
    if (http_conn_wait(&ctx, 3, 30000) != 0)
        return finish(&ctx, tls, -1);
    return finish(&ctx, tls, parse_response(&ctx, out));
}
```

- [ ] **Step 6: Extend `CMakeLists.txt`** — add `src/http_conn.c` and `src/http_client.c` to sources; `target_link_libraries` gains `pico_lwip_mbedtls` and `pico_mbedtls`.
- [ ] **Step 7: Build** — expected `.uf2` builds. Known friction points: `altcp_tls_context()` needs `lwip/altcp_tls.h` (already included); if `mbedtls_ssl_set_hostname` is undeclared, include `mbedtls/ssl.h` (http_conn.c does). Fix include/lib issues here — do not change the module interfaces.
- [ ] **Step 8: Commit** — `feat: https post client over altcp_tls with optional ca pinning`.

---

### Task 18: `odoo_client` — auth + fetch orchestration

**Files:**
- Create: `include/odoo_client.h`, `src/odoo_client.c`
- Modify: `CMakeLists.txt`

**Interfaces:**
- Consumes: `odoo_request`, `odoo_parse`, `http_client`.
- Produces: `int odoo_client_sync(int *uid, struct odoo_task_list *list);` — authenticates when `*uid <= 0`, fetches tasks, re-authenticates+retries once when Odoo returns an error object (-2). Returns 0 ok / -1 failed.

- [ ] **Step 1: Create `include/odoo_client.h`**

```c
/*
** EPITECH PROJECT, 2026
** epaper_dashboard
** File description:
** Odoo sync orchestration: authenticate, fetch tasks, re-auth on error
*/

#ifndef ODOO_CLIENT_H_
    #define ODOO_CLIENT_H_

    #include "odoo.h"

int odoo_client_sync(int *uid, struct odoo_task_list *list);

#endif /* !ODOO_CLIENT_H_ */
```

- [ ] **Step 2: Create `src/odoo_client.c`**

```c
/*
** EPITECH PROJECT, 2026
** epaper_dashboard
** File description:
** Odoo sync orchestration: authenticate, fetch tasks, re-auth on error
*/

#include <stdio.h>
#include "http_client.h"
#include "odoo_client.h"
#include "odoo_parse.h"
#include "odoo_request.h"

static int do_auth(int *uid)
{
    static char body[ODOO_REQ_CAP];
    struct http_response resp = {0, 0, 0};

    if (odoo_build_auth(body, sizeof(body)) < 0)
        return -1;
    if (http_post_json("/jsonrpc", body, &resp) != 0)
        return -1;
    if (odoo_parse_auth(resp.body, resp.body_len, uid) != 0)
        return -1;
    printf("odoo: authenticated uid=%d\n", *uid);
    return 0;
}

static int do_fetch(int uid, struct odoo_task_list *list)
{
    static char body[ODOO_REQ_CAP];
    struct http_response resp = {0, 0, 0};

    if (odoo_build_tasks(body, sizeof(body), uid) < 0)
        return -1;
    if (http_post_json("/jsonrpc", body, &resp) != 0)
        return -1;
    return odoo_parse_tasks(resp.body, resp.body_len, list);
}

int odoo_client_sync(int *uid, struct odoo_task_list *list)
{
    int ret = 0;

    if (*uid <= 0 && do_auth(uid) != 0)
        return -1;
    ret = do_fetch(*uid, list);
    if (ret == -2 && do_auth(uid) == 0)
        ret = do_fetch(*uid, list);
    return ret == 0 ? 0 : -1;
}
```

- [ ] **Step 3: Extend `CMakeLists.txt`** — add `src/odoo_client.c` to sources.
- [ ] **Step 4: Build** — expected `.uf2` builds (odoo_client not yet called from main; that's Task 19).
- [ ] **Step 5: Commit** — `feat: odoo sync orchestration with automatic re-authentication`.

---
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

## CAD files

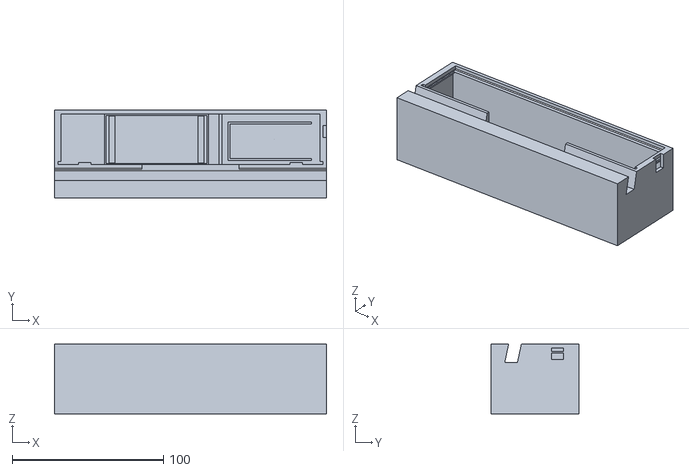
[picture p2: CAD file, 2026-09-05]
hardware/epaper73_base.stl
180.0 x 58.0 x 46.0

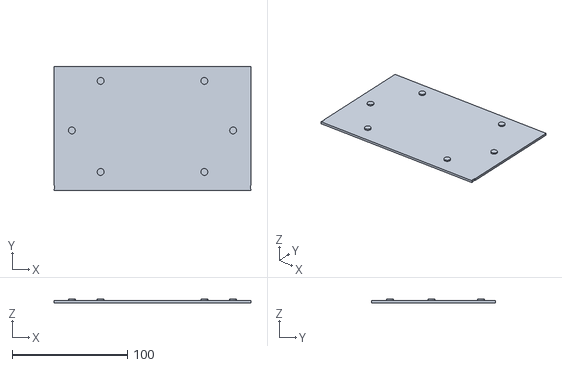
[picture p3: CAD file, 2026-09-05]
hardware/print/epaper73_plate_print.stl
171.0 x 107.4 x 3.10

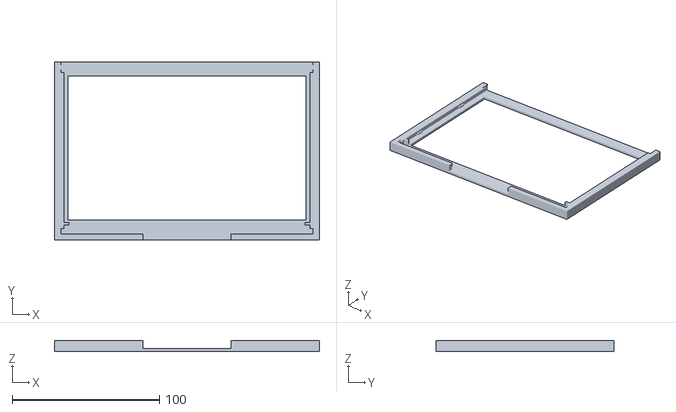
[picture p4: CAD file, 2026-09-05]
hardware/print/epaper73_frame_print.stl
180.0 x 121.2 x 7.60

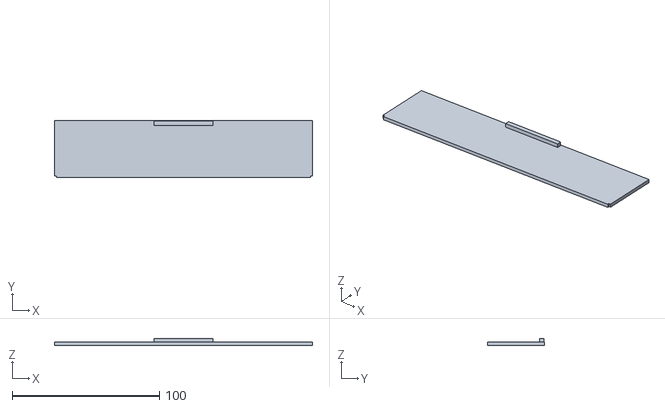
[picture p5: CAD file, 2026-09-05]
hardware/epaper73_lid.stl
175.0 x 39.0 x 4.70

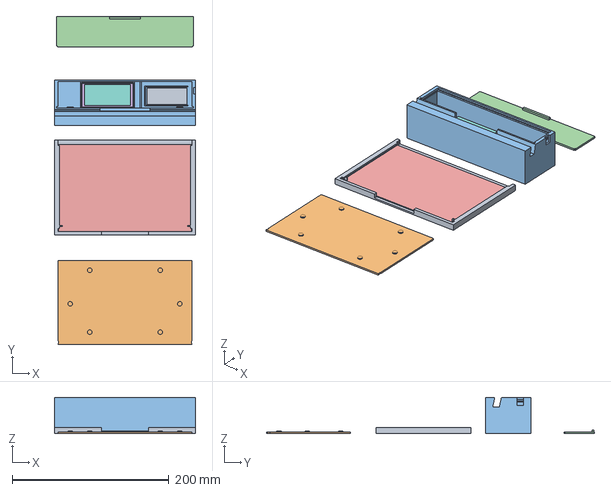
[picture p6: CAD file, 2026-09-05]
hardware/epaper73_case.step
180.0 x 419.0 x 46.0 mm

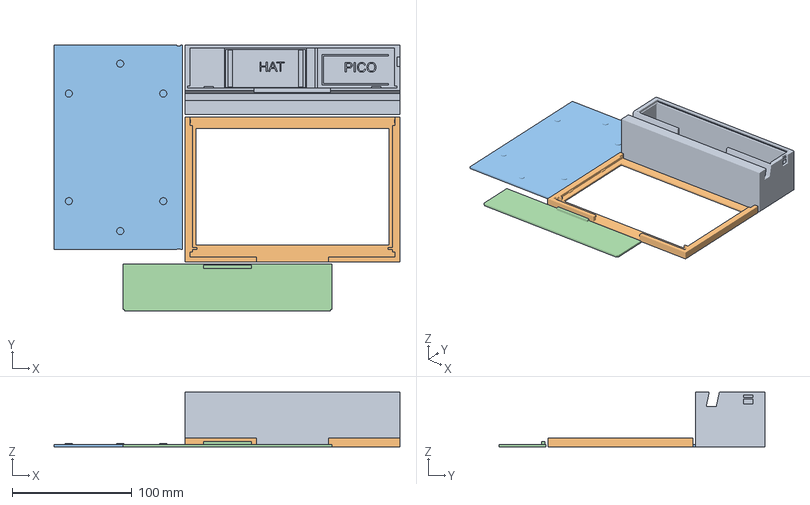
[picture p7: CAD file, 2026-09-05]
hardware/print/epaper73_H2C_PLA.3mf
289.4 x 222.2 x 46.0 mm
epaper73_base_print.stl
epaper73_frame_print.stl
epaper73_plate_print.stl
epaper73_lid_print.stl

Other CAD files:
hardware/epaper73_plate.stl
hardware/print/epaper73_lid_print.stl
hardware/epaper73_frame.stl
hardware/print/epaper73_base_print.stl

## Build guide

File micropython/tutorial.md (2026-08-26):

# Tutoriel : écran Waveshare 7.3" e-Paper HAT (E) + Raspberry Pi Pico 2 W (headers)

Ton matériel confirmé : **Pico 2 W** (puce RP2350, 520 Ko de RAM — parfait pour cet écran), HAT (E) avec câble **8 fils**, et interrupteur **SPI Select** sur le HAT.

---

## Étape 1 — Le matériel et comment il s'assemble

- **Le panneau e-paper 7.3"** : relié au HAT par la grande nappe blanche (FFC). Sur ta photo elle est déjà connectée des deux côtés — vérifie juste qu'elle est insérée bien droite et à fond, loquets fermés.
- **Le HAT bleu** : c'est l'interface entre l'écran et le microcontrôleur.
- **Le câble blanc 8 fils (PH2.0 → Dupont femelle)** : c'est le lien HAT ↔ Pico.
- **Ton Pico 2 W avec headers** : les fils Dupont femelles s'enfichent directement sur ses broches.

> **Pourquoi on ne branche pas le HAT directement sur le Pico :** le connecteur 40 broches du HAT est prévu pour le brochage d'un Raspberry Pi "classique" (Pi 4/5/Zero). Le Pico a aussi 40 broches, mais dans un ordre totalement différent — le brancher dessus enverrait du courant au mauvais endroit. Avec un Pico, on passe **toujours** par le câble 8 fils. C'est le montage normal, tu ne rates rien.

---

## Étape 2 — L'interrupteur "SPI Select" : position 0

Sur le HAT, à côté du connecteur de nappe, il y a un petit interrupteur **SPI Select** avec deux positions sérigraphiées :
- `1` = 3-line SPI
- `0` = **4-line SPI ← c'est celle qu'il te faut**

Le mode 4 fils utilise la broche DC (Data/Command), comme le fait le code standard Waveshare et le script fourni. Vérifie qu'il est sur **0** avant de commencer.

---

## Étape 3 — Câblage des 8 fils vers le Pico

Branche le connecteur blanc PH2.0 sur le HAT (un seul sens possible). Les noms des signaux sont **sérigraphiés sur le HAT** à côté du connecteur : fie-toi à eux en priorité. Les couleurs Waveshare habituelles sont indiquées ci-dessous à titre de repère (elles correspondent à ton câble) :

| Signal HAT | Couleur (habituelle) | Broche Pico 2 W | N° physique |
|---|---|---|---|
| VCC | Gris | 3V3 (OUT) | 36 |
| GND | Marron | GND | 38 (ou n'importe quel GND) |
| DIN | Bleu | GP11 | 15 |
| CLK | Jaune | GP10 | 14 |
| CS | Orange | GP9 | 12 |
| DC | Vert | GP8 | 11 |
| RST | Blanc | GP12 | 16 |
| BUSY | Violet | GP13 | 17 |

**Comment retrouver GP8–GP13 sur ton Pico :** les noms sont sérigraphiés **au dos** de la carte (visibles sur ta 2e photo : GP8, GP9, GND, GP10, GP11, GP12, GP13 sont alignés sur le même côté, dans la moitié opposée à l'USB). C'est pratique : tous les fils de signaux vont sur des broches voisines. 3V3(OUT) et le GND de la broche 38 sont sur l'autre rangée, côté USB.

**Règle de sécurité :** jamais de fil du HAT sur VBUS ou VSYS (5 V). L'écran fonctionne en 3,3 V uniquement.

Double-vérifie DIN/CLK et CS/DC (les inversions classiques) avant de brancher l'USB.

---

## Étape 4 — Flasher MicroPython sur le Pico 2 W

Le Pico n'a pas de système d'exploitation : on y installe un firmware une fois, puis on y dépose des scripts. "Flasher" est très simple :

1. Va sur **micropython.org/download/RPI_PICO2_W** et télécharge le fichier `.uf2` le plus récent (bien la version **Pico 2 W**, pas Pico W ni Pico 2).
2. **Maintiens le bouton blanc BOOTSEL** du Pico enfoncé.
3. Tout en le maintenant, branche le câble micro-USB à ton ordi, puis relâche le bouton.
4. Un disque amovible apparaît sur ton ordi (nommé `RP2350`).
5. Glisse-dépose le fichier `.uf2` dessus. Le disque disparaît tout seul : MicroPython est installé. ✅

C'est réversible à volonté et impossible à rater définitivement : au pire, on recommence l'opération BOOTSEL.

> Attention : utilise un câble micro-USB **de données** (certains câbles de charge n'ont pas les fils data et le Pico ne sera jamais détecté).

---

## Étape 5 — Installer Thonny et vérifier la connexion

1. Télécharge **Thonny** (thonny.org) et installe-le.
2. Branche le Pico normalement (sans BOOTSEL cette fois).
3. Dans Thonny, en bas à droite, clique sur la zone de l'interpréteur → choisis **"MicroPython (Raspberry Pi Pico)"** et le port proposé.
4. La console du bas doit afficher un prompt `>>>`. Tape `print("hello")` : si ça répond, la chaîne complète ordi ↔ Pico fonctionne.

---

## Étape 6 — Premier affichage 🎉

1. Ouvre le fichier **`main_epd7in3e.py`** (fourni avec ce tutoriel) dans Thonny.
2. Clique sur le **triangle vert** (Exécuter le script courant).
3. L'écran va rester gris puis **clignoter/flasher pendant ~20-30 s** : c'est le cycle de rafraîchissement normal d'un e-paper couleur, pas un bug.
4. Résultat attendu : bandes de couleurs (noir, rouge, jaune, bleu, vert), quelques formes, et un texte de bienvenue.

Pour que ton programme se lance automatiquement à chaque mise sous tension (sans ordinateur) : dans Thonny, **Fichier → Enregistrer sous… → Raspberry Pi Pico**, nomme le fichier **`main.py`**. Le Pico exécute toujours `main.py` au démarrage.

### Ce que fait le script
- Il embarque un **driver minimal** pour le contrôleur de l'écran (adapté du code officiel Waveshare `epd7in3e`)
- Il crée un framebuffer 800×480 en 6 couleurs (~192 Ko, à l'aise dans les 520 Ko du Pico 2 W)
- Il dessine, envoie l'image, puis met l'écran **en veille** (indispensable, voir ci-dessous)

---

## ⚠️ Règles d'or pour ne pas abîmer l'écran

- **Toujours terminer par `epd.sleep()`** (le script le fait). Laisser l'écran alimenté hors veille le maintient sous haute tension interne → dommages irréversibles.
- En usage régulier, espace les rafraîchissements d'**au moins 3 minutes**.
- S'il reste alimenté, rafraîchis-le **au moins une fois par 24 h** ; efface-le en blanc avant un stockage prolongé.
- Écran couleur = plage idéale **15–35 °C**, évite le plein soleil prolongé.
- Ne jamais brancher/débrancher les fils quand le Pico est sous tension.

---

## Dépannage rapide

| Symptôme | Piste |
|---|---|
| Aucun clignotement au lancement | VCC sur 3V3 (broche 36) ? GND commun ? Nappe FFC bien insérée ? Interrupteur SPI Select sur 0 ? |
| Le script bloque sur l'attente "busy" | BUSY bien sur GP13, RST sur GP12 ; vérifie CS/DC non inversés |
| Thonny ne détecte pas le Pico | Câble USB de charge seulement → prends un câble data ; refais BOOTSEL avec le `.uf2` RPI_PICO2_W |
| Image décalée / couleurs fausses | Nappe FFC de travers, ou fils DIN/CLK inversés |
| `MemoryError` | Firmware Pico W flashé par erreur au lieu de Pico 2 W |

Si le driver fourni pose souci, le code officiel est dans les ressources de la page wiki Waveshare « 7.3inch e-Paper HAT (E) ».

---

## Et ensuite ?

Ton Pico 2 W a le Wi-Fi : idées de suite naturelles → tableau de bord météo, agenda du jour, citations, cadre photo (avec conversion des images en 6 couleurs + dithering côté ordinateur). Le framebuffer te donne déjà `text()`, `line()`, `rect()`, `fill_rect()`, `ellipse()`, `pixel()`.

Bon montage ! 🚀

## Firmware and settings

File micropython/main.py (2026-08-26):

# -----------------------------------------------------------------------------
# Waveshare 7.3" e-Paper HAT (E) - Spectra 6 couleurs - 800x480
# Driver MicroPython pour Raspberry Pi Pico 2 W (RP2350)
#
# Transport : BIT-BANG PUR (aucun SPI materiel).
# C'est exactement la methode qui a fait clignoter ton ecran au test
# d'autodetection. Plus lent (~15-20 s d'envoi) mais fiable sur ton cablage.
#
# Cablage (SPI Select sur 0) :
#   VCC(gris)->3V3(36)  GND(marron)->GND  DIN(bleu)->GP11  CLK(jaune)->GP10
#   CS(orange)->GP9  DC(vert)->GP8  RST(blanc)->GP12  BUSY(violet)->GP13
# -----------------------------------------------------------------------------

from machine import Pin
import framebuf
import time

RST_PIN = 12
DC_PIN = 8
CS_PIN = 9
BUSY_PIN = 13
CLK_PIN = 10
DIN_PIN = 11

EPD_WIDTH = 800
EPD_HEIGHT = 480

# Couleurs (4 bits/pixel) - codes du controleur Spectra 6
BLACK = 0x0
WHITE = 0x1
YELLOW = 0x2
RED = 0x3
BLUE = 0x5
GREEN = 0x6


class EPD_7in3E:
    def __init__(self):
        self.reset_pin = Pin(RST_PIN, Pin.OUT)
        self.busy_pin = Pin(BUSY_PIN, Pin.IN, Pin.PULL_UP)
        self.cs_pin = Pin(CS_PIN, Pin.OUT, value=1)
        self.dc_pin = Pin(DC_PIN, Pin.OUT, value=0)
        self.clk_pin = Pin(CLK_PIN, Pin.OUT, value=0)
        self.din_pin = Pin(DIN_PIN, Pin.OUT, value=0)

        self.width = EPD_WIDTH
        self.height = EPD_HEIGHT
        self.buffer = bytearray(self.width * self.height // 2)
        self.image = framebuf.FrameBuffer(
            self.buffer, self.width, self.height, framebuf.GS4_HMSB
        )

        # Init avec verification que l'ecran reagit vraiment (jusqu'a 3 essais)
        ok = False
        for attempt in range(3):
            self.reset()
            self._wait_idle_short()
            self._send_init()
            if self._power_on_reacts():
                ok = True
                break
            print("  (essai %d : pas de reaction, nouvelle tentative...)" % (attempt + 1))
            time.sleep_ms(200)
        if not ok:
            raise RuntimeError(
                "L'ecran ne reagit pas. Reenfonce fermement chaque fil "
                "CLK/DIN/DC/CS (contact intermittent le plus probable), "
                "puis relance."
            )

    # --- Bas niveau bit-bang (SPI mode 0, MSB first) --------------------------
    def reset(self):
        self.reset_pin(1); time.sleep_ms(20)
        self.reset_pin(0); time.sleep_ms(2)
        self.reset_pin(1); time.sleep_ms(20)

    def _tx(self, data):
        clk = self.clk_pin
        din = self.din_pin
        for b in data:
            din((b >> 7) & 1); clk(1); clk(0)
            din((b >> 6) & 1); clk(1); clk(0)
            din((b >> 5) & 1); clk(1); clk(0)
            din((b >> 4) & 1); clk(1); clk(0)
            din((b >> 3) & 1); clk(1); clk(0)
            din((b >> 2) & 1); clk(1); clk(0)
            din((b >> 1) & 1); clk(1); clk(0)
            din(b & 1);        clk(1); clk(0)

    def send_command(self, cmd):
        self.dc_pin(0); self.cs_pin(0)
        self._tx(bytes([cmd]))
        self.cs_pin(1)

    def send_data(self, data):
        self.dc_pin(1); self.cs_pin(0)
        if isinstance(data, int):
            self._tx(bytes([data]))
        else:
            self._tx(data)
        self.cs_pin(1)

    def _wait_idle_short(self, timeout_ms=5000):
        time.sleep_ms(30)
        t = time.ticks_ms()
        while self.busy_pin.value() == 0:
            if time.ticks_diff(time.ticks_ms(), t) > timeout_ms:
                return
            time.sleep_ms(10)

    def wait_until_idle(self, timeout_ms=60_000):
        time.sleep_ms(50)
        t = time.ticks_ms()
        while self.busy_pin.value() == 0:
            if time.ticks_diff(time.ticks_ms(), t) > timeout_ms:
                raise RuntimeError("Timeout BUSY (>%d s)" % (timeout_ms // 1000))
            time.sleep_ms(20)

    def _power_on_reacts(self, watch_ms=3000):
        # power-on, et verifie que BUSY passe a 0 (l'ecran se met au travail)
        self.send_command(0x04)
        t = time.ticks_ms()
        while time.ticks_diff(time.ticks_ms(), t) < watch_ms:
            if self.busy_pin.value() == 0:
                self.wait_until_idle()
                return True
            time.sleep_ms(2)
        return False

    # --- Init officielle epd7in3e ---------------------------------------------
    def _send_init(self):
        self.send_command(0xAA)
        self.send_data(bytearray([0x49, 0x55, 0x20, 0x08, 0x09, 0x18]))
        self.send_command(0x01); self.send_data(0x3F)
        self.send_command(0x00); self.send_data(bytearray([0x5F, 0x69]))
        self.send_command(0x03); self.send_data(bytearray([0x00, 0x54, 0x00, 0x44]))
        self.send_command(0x05); self.send_data(bytearray([0x40, 0x1F, 0x1F, 0x2C]))
        self.send_command(0x06); self.send_data(bytearray([0x6F, 0x1F, 0x17, 0x49]))
        self.send_command(0x08); self.send_data(bytearray([0x6F, 0x1F, 0x1F, 0x22]))
        self.send_command(0x30); self.send_data(0x03)
        self.send_command(0x50); self.send_data(0x3F)
        self.send_command(0x60); self.send_data(bytearray([0x02, 0x00]))
        self.send_command(0x61); self.send_data(bytearray([0x03, 0x20, 0x01, 0xE0]))
        self.send_command(0x84); self.send_data(0x01)
        self.send_command(0xE3); self.send_data(0x2F)

    # --- Affichage ------------------------------------------------------------
    def turn_on_display(self):
        self.send_command(0x04); self.wait_until_idle()   # power on
        self.send_command(0x12); self.send_data(0x00)      # refresh
        self.wait_until_idle()
        self.send_command(0x02); self.send_data(0x00)      # power off
        self.wait_until_idle()

    def display(self):
        self.send_command(0x10)
        self.send_data(self.buffer)
        self.turn_on_display()

    def clear(self, color=WHITE):
        self.image.fill(color)
        self.display()

    def sleep(self):
        self.send_command(0x07)
        self.send_data(0xA5)
        time.sleep_ms(20)


# --- Texte agrandi (police framebuf native = 8 px, trop petite en 800x480) ----
def big_text(fb, s, x, y, color, scale=2):
    w = len(s) * 8
    tmp_buf = bytearray(w * 8 // 2 + 8)
    tmp = framebuf.FrameBuffer(tmp_buf, w, 8, framebuf.GS4_HMSB)
    tmp.fill(WHITE)
    tmp.text(s, 0, 0, BLACK)
    for dy in range(8):
        for dx in range(w):
            if tmp.pixel(dx, dy) != WHITE:
                fb.fill_rect(x + dx * scale, y + dy * scale, scale, scale, color)


def big_text_centered(fb, s, y, color, scale=2, x0=0, width=EPD_WIDTH):
    x = x0 + (width - len(s) * 8 * scale) // 2
    big_text(fb, s, x, y, color, scale)


# ==============================================================================
# Bienvenue + test des 6 couleurs (une bande legendee par couleur)
# ==============================================================================
if __name__ == "__main__":
    epd = None
    try:
        print("Initialisation de l'ecran (bit-bang)...")
        epd = EPD_7in3E()

        print("Composition de l'image...")
        epd.image.fill(WHITE)

        big_text_centered(epd.image, "Bienvenue !", 25, BLACK, scale=4)
        big_text_centered(epd.image, "Test des 6 couleurs - Waveshare 7.3 (E)", 95, RED, scale=2)

        bands = [
            (BLACK, "NOIR", WHITE),
            (WHITE, "BLANC", BLACK),
            (YELLOW, "JAUNE", BLACK),
            (RED, "ROUGE", WHITE),
            (BLUE, "BLEU", WHITE),
            (GREEN, "VERT", WHITE),
        ]
        top = 130
        bh = EPD_HEIGHT - top
        bw = EPD_WIDTH // len(bands)
        for i, (color, label, txt) in enumerate(bands):
            x = i * bw
            epd.image.fill_rect(x, top, bw, bh, color)
            epd.image.rect(x, top, bw, bh, BLACK)
            lx = x + (bw - len(label) * 8 * 2) // 2
            big_text(epd.image, label, lx, top + 30, txt, scale=2)

        print("Envoi (bit-bang, ~15-20 s) puis rafraichissement (~20-30 s)...")
        epd.display()
        print("Affichage termine !")

    finally:
        if epd:
            print("Mise en veille de l'ecran (obligatoire).")
            epd.sleep()

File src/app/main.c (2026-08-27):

/*
** Charles Le Maux, 2026
** epaper_dashboard
** File description:
** Boot sequence and superloop: poll odoo, refresh the panel on change
*/

#include <stdio.h>
#include "pico/stdlib.h"
#include "pico/cyw43_arch.h"
#include "hardware/watchdog.h"
#include "app.h"
#include "config.h"
#include "dashboard.h"
#include "epd.h"
#include "net_time.h"
#include "net_wifi.h"
#include "odoo_client.h"
#include "panic_log.h"
#include "sys_idle.h"
#include "time_fmt.h"

static uint32_t now_s(void)
{
    return (uint32_t)(to_us_since_boot(get_absolute_time()) / 1000000ull);
}

static void fatal_blink(void)
{
    for (;;) {
        net_wifi_led(1);
        sleep_ms(100);
        net_wifi_led(0);
        sleep_ms(100);
    }
}

static void wifi_boot(void)
{
    uint32_t backoff = 5000;

    while (net_wifi_connect() != 0) {
        printf("wifi: retry in %u ms\n", (unsigned int)backoff);
        sys_idle_ms(backoff);
        backoff = backoff < 80000 ? backoff * 2 : 80000;
    }
    printf("wifi: connected\n");
}

static void time_boot(void)
{
    net_time_init();
    while (net_time_synced() == 0)
        sys_idle_ms(500);
    printf("time: synced\n");
}

static void note_result(struct app *app, int ret)
{
    struct tm lt;

    if (ret == 0) {
        app->fails = 0;
        app->current.offline = 0;
        printf("odoo: %u activities\n", app->current.list.count);
        return;
    }
    app->fails++;
    app->current.list = app->displayed.list;
    printf("odoo: fetch failed (%u in a row)\n", app->fails);
    if (app->fails == 3) {
        app->current.offline = 1;
        net_time_local(&lt);
        time_fmt_hhmm(app->offline_since, sizeof(app->offline_since),
            &lt);
    }
}

static int display_frame(struct app *app)
{
    int ret = 0;

    printf("epd: refresh start\n");
    if (epd_init() != 0) {
        printf("epd: panel not responding\n");
        return -1;
    }
    ret = epd_display(app->fb);
    epd_sleep();
    printf("epd: refresh %s\n", ret == 0 ? "done" : "failed");
    return ret;
}

static void apply_refresh(struct app *app)
{
    struct dashboard_data data;
    struct tm lt;

    data.snap = &app->current;
    net_time_local(&lt);
    data.today = lt;
    time_fmt_banner(data.banner_date, sizeof(data.banner_date), &lt);
    time_fmt_hhmm(data.updated_hhmm, sizeof(data.updated_hhmm), &lt);
    snprintf(data.offline_since, sizeof(data.offline_since), "%s",
        app->offline_since);
    dashboard_render(app->fb, &data);
    if (display_frame(app) != 0)
        return;
    app->displayed = app->current;
    app->last_refresh_s = now_s();
    app->has_displayed = 1;
}

static void poll_once(struct app *app)
{
    struct refresh_times t = {now_s(), app->last_refresh_s,
        app->has_displayed};
    int ret = 0;

    if (net_wifi_up() == 0)
        net_wifi_connect();
    ret = odoo_client_sync(&app->uid, &app->current.list);
    note_result(app, ret);
    if (ret != 0 && app->fails < 3)
        return;
    if (refresh_needed(&app->displayed, &app->current, &t) != 0)
        apply_refresh(app);
}

int main(void)
{
    static struct app app;

    stdio_init_all();
    sleep_ms(2000);
    panic_log_report();
    watchdog_enable(8000, 1);
    if (net_wifi_init() != 0)
        fatal_blink();
    epd_io_init();
    wifi_boot();
    time_boot();
    for (;;) {
        poll_once(&app);
        sys_idle_ms((uint32_t)POLL_INTERVAL_S * 1000u);
    }
    return 0;
}

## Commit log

2026-08-26 Add design spec for C rewrite of the Odoo e-paper dashboard
    Initial commit: validated MicroPython reference implementation,
    driver documentation, and the approved design for the bare-metal
    C firmware (Pico SDK, HTTPS JSON-RPC polling, refresh-on-change).
2026-08-26 Add implementation plan for the C firmware
    21 bite-sized tasks: toolchain bootstrap, scaffold, TDD of the nine
    host-testable modules, driver port, network bring-up, TLS client,
    superloop integration, docs and style audit.
2026-08-26 feat: minimal Pico 2 W firmware skeleton builds a uf2
2026-08-26 feat: 4bpp framebuffer fill, pixel and rectangle primitives
2026-08-26 feat: port validated e-paper driver to paced bit-bang C
2026-08-26 fix: guard time_fmt.c GCC pragma to real GCC only
    Coordinator review flagged a portability risk: the GCC-only
    -Wformat-truncation pragma added for Task 14 names a warning
    Clang does not implement. Clang currently tolerates unknown
    warning names inside GCC-style pragmas silently (undocumented,
    implementation-specific leniency), so the host test suite
    (clang -Werror) already passed unguarded — verified before this
    change. Guarding the pragma to #if defined(__GNUC__) &&
    !defined(__clang__) removes reliance on that leniency without
    changing make_iso's behavior on either toolchain.
2026-08-26 feat: sntp time sync stored in the always-on timer
2026-08-26 chore: integrate pico vscode extension project files
2026-08-26 fix: harden dns callback lifetime, tls rsa key exchange, close and clock
    [main.c]
2026-08-26 fix: size lwip timeout pool for sntp+tcp, capture panics across reboot
    The default MEMP_SYS_TIMEOUT pool (6) counts only lwIP-internal users;
    five cyclic timers plus the SNTP app timer filled it at boot, so the
    first TCP connection's lazily-registered timer hit the empty pool and
    tripped the sys_timeout assert -> panic on the first HTTPS poll.
    Panic messages die with the USB port on this headless device, so panics
    are now stored in noinit RAM via PICO_PANIC_FUNCTION and reported as
    "last panic: ..." on the next boot.
    [main.c]
2026-08-26 feat: make the undated-todos filter a config boolean
    ODOO_TASK_DOMAIN returns to the plain base filter; when
    ODOO_INCLUDE_UNDATED_TODOS is 0 (default) the firmware appends the
    project-or-deadline clause at request-build time. Setting it to 1
    restores every personal to-do. Covered by a second test binary
    compiled with the flag enabled.
2026-08-26 chore: replace school header banner with author name
    All file headers now read "Charles Le Maux, 2026"; the style
    checker's header regex follows.
    [epd.h, epd_io.c]
2026-08-26 refactor: organize sources and headers into feature subfolders
    src/ and include/ now mirror six feature groups: app (superloop,
    dashboard, refresh policy, time formatting, panic log, idle), epd
    (panel driver), gfx (framebuffer drawing), json (parsing utilities),
    net (wifi, sntp, http/tls), odoo (request building, response parsing,
    sync orchestration). Include search paths cover the subfolders, so
    include directives stay unchanged. include/config.h stays at the
    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
2026-08-26 feat: rename todo switch to ODOO_INCLUDE_DATED_TODOS
    The switch now gates whether to-dos appear at all: 1 (default) shows
    project tasks plus dated to-dos, 0 shows project tasks only. Undated
    to-dos never appear in either mode — the firmware always appends a
    domain filter, either project-or-deadline or project-only. Both
    branches covered by the two request-builder test binaries.
2026-08-26 feat: replace bitmap font with embedded Questrial, green banner
    The 8x8 scaled font gives way to Questrial (SIL OFL 1.1), pre-rendered
    by tools/gen_font.py into proportional 16px and 24px bitmap glyph
    tables compiled into the firmware; gfx_text draws them 1:1, with the
    style scale field now selecting the face (>=3 -> 24px). Text width and
    centering are metrics-aware. The banner background turns green. A host
    preview tool (tests: make preview.exe) renders a sample frame for
    visual checks without flashing.
2026-08-26 feat: scale ui to 32/48px type with name-first adaptive rows
    Fonts regenerate at 32px (body) and 48px (headlines); the layout grows
    to a 72px banner, seven 48px rows and a 32px footer, so the fetch
    limit drops to 8. Rows are rebuilt around priorities: the task name
    gets the width, the deadline is always pinned far right, and leftover
    space auto-fills with overdue days (retard Nj), project and stage,
    appending only pieces that fit. Names that overflow truncate with an
    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
2026-09-05 feat: planning title, true activity total, counted overflow footer
    The banner is retitled Planning and its counter now shows the real
    number of scheduled activities: the client runs a search_count on the
    same domain next to the row fetch and stores it in the snapshot, so
    the fetch limit drops back to exactly seven rows and the limit-spill
    overflow flag disappears. When more activities exist than fit, the
    footer spells out how many: + d'autres activites (N).
    [epaper73_H2C_PLA.3mf, epaper73_base.stl, epaper73_base_print.stl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]
2026-10-05 feat(rust): port 4bpp framebuffer primitives
2026-10-05 feat(rust): byte-exact frame parity against the c renderer
2026-10-05 feat(rust): port paced bit-bang e-paper driver
2026-10-20 feat(refresh): redraw the panel on the first poll after local midnight
    The banner date, overdue deadlines and day counters depend on the local
    date, but the policy only compared the activity list and offline flag, so
    an unchanged Odoo list left yesterday's date on screen for up to 24 h.
    RefreshTimes now carries the drawn day and today's local date; a date
    change counts as a change. MIN_GAP_S and MAX_AGE_S are unchanged, and the
    midnight redraw resets the age timer like any other.
